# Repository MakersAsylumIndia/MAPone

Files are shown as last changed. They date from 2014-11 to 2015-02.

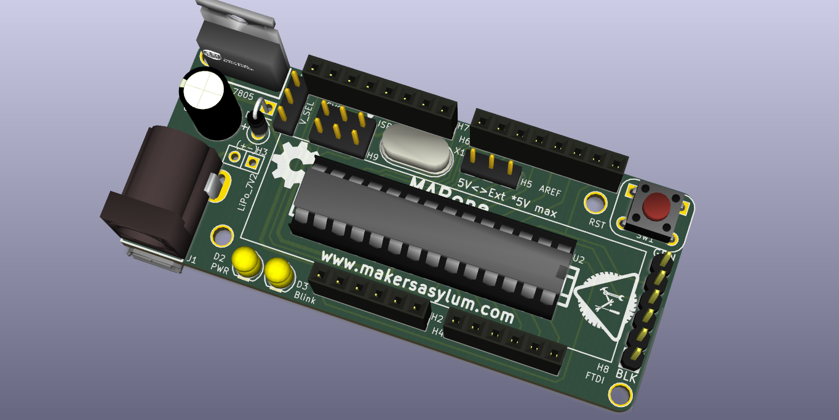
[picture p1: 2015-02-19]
images/MAPone_20.png

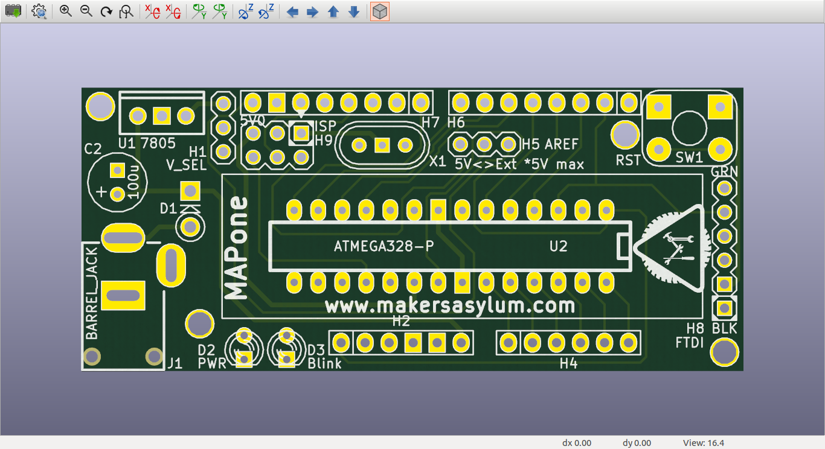
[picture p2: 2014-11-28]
images/MAPone_06.png

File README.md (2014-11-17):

MAPone
======

A really bare bones Arduino using ATMega 328P DIP, SPI and Serial Interfaces and a few LEDs. Arduino stripped down to bare basics so everyone can afford it.

License
-------
[CERN Open Hardware Licence v1.2 ]

[CERN Open Hardware Licence v1.2 ]:http://www.ohwr.org/attachments/2388/cern_ohl_v_1_2.txt

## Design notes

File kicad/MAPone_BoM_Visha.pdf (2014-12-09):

MAPone_BoM

Qty Catalog | Part Value | Part Package | Link
1 | 5 Capacitor | 100nF, 50V | CL21B104KBCNNNC
2 | 1 Capacitor | 100uF, 35V | Kemet | ESK107M035AE3AA
3 | 2 Capacitor | 22pF, 50V | CL21C220JBANFNC
4 | 1 Diode | 1N4007 | 1N4007-TP
5 | 1 Led | LED PWR | Kingbright | WP710A10ID
6 | 1 Led | LED_BLINK | Kingbright | WP710A10GD
7 | 1 Connector | BARREL_JACK | CUI Inc | PJ-002A

Item
No

Part
Description

Manufacturers
Name

Manufacturers
Part No.

CAP CER
0.1UF 50V
10% X7R 0805

0805
(2012 Metric)

Samsung
Electro-Mechanics
America, Inc

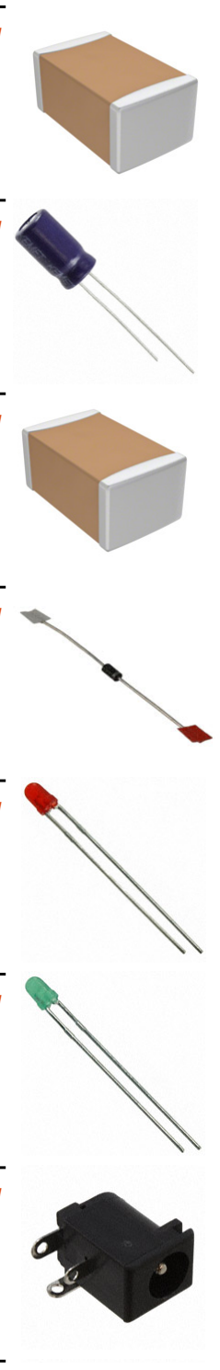
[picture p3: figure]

http://www.digikey.com/product-detail/en/CL21B104KBCNNNC/1276-1003-1-ND/3889089

CAP ALUM
100UF 35V
20% RADIAL

2.5mm pitch,
Radial

http://www.digikey.com/product-detail/en/ESK107M035AE3AA/399-6104-ND/2712510

CAP CER
22PF 50V
5% NP0 0805

0805
(2012 Metric)

Samsung
Electro-Mechanics
America, Inc

http://www.digikey.com/product-detail/en/CL21C220JBANFNC/1276-2606-1-ND/3890692

DIODE GEN
PURPOSE
1000V 1A DO41

DO-204AL,
DO-41,
Axial

Micro
Commercial Co

http://www.digikey.com/product-detail/en/1N4007-TP/1N4007-TPMSCT-ND/773694

LED RED DIFF
3MM 625NM

Round with
Domed Top,
3mm, T-1

http://www.digikey.com/product-detail/en/WP710A10ID/754-1606-ND/2769809

LED GREEN DIFF
3MM 568NM

Round with
Domed Top,
3mm, T-1

http://www.digikey.com/product-detail/en/WP710A10GD/754-1603-ND/2769808

CONN POWER JACK
2.1MM X 5.5MM

2.1mm ID,
5.5mm OD,
3 terminals

http://www.digikey.com/product-detail/en/PJ-002A/CP-002A-ND/96962

8 | 1 Connector | USB_Micro | FCI | 10118193-0001LF
9 | 1 Resistor | 10k | RMCF0805FT10K0
10 | 2 Resistor | 300E | ERJ-6GEYJ301V
11 | 1 Switch | SW_RST | 6.00mm x 6.00mm | 1825910-6
12 | 1 IC | 7805 | TO-220-3 | NCP7805TG
13 | 1 IC | Atmega328p | Atmel | ATMEGA328-PU
14 | 1 Crystal | Xtal_16MHz | 9B-16.000MBBK-B
15 | 1 Connector | PREC040SAAN-RC

CONN USB MICRO B
RECPT SMT R/A

Surface Mount,
Right Angle,
Horizontal
REFER DATA
SHEET

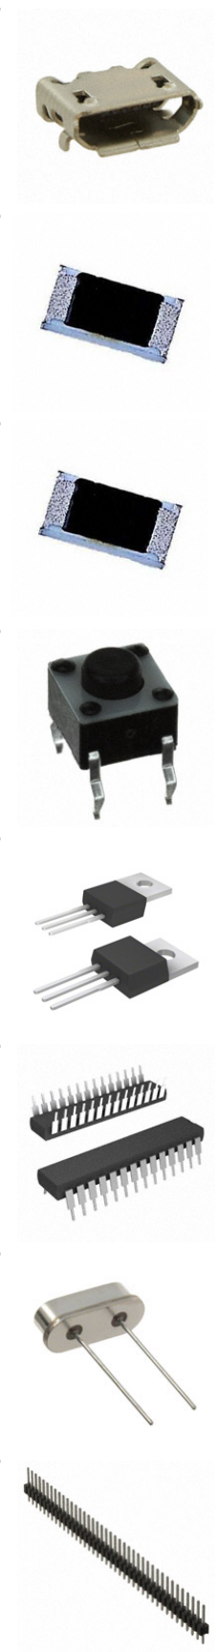
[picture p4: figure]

http://www.digikey.com/product-detail/en/10118193-0001LF/609-4616-1-ND/2785380

RES SMD 10K OHM
1% 1/8W 0805

0805
(2012 Metric)

Stackpole
Electronics
Inc

http://www.digikey.com/product-detail/en/RMCF0805FT10K0/RMCF0805FT10K0CT-ND/1942435

RES SMD 300 OHM
5% 1/8W 0805

0805
(2012 Metric)

Panasonic
Electronic
Components

http://www.digikey.com/product-detail/en/ERJ-6GEYJ301V/P300ACT-ND/90024

SWITCH TACTILE
SPST-NO
0.05A 12V

TE
Connectivity

http://www.digikey.com/product-detail/en/1825910-6/450-1650-ND/1632536

IC REG LDO
5V 1A TO220AB

ON
Semiconductor

http://www.digikey.com/product-detail/en/NCP7805TG/NCP7805TGOS-ND/2271529

IC MCU 8BIT 32KB
FLASH 28DIP

28-DIP
(0.300", 7.62mm)

http://www.digikey.com/product-detail/en/ATMEGA328-PU/ATMEGA328-PU-ND/2271026

CRYSTAL
16MHZ 20PF
THRU HOLE

Through Hole,
HC49/US, 0.2”
pitch

TXC
CORPORATION

http://www.digikey.com/product-detail/en/9B-16.000MBBK-B/887-2015-ND/3522089

Male Header,
0.1”

V_SEL, AREF,
FTDI

Header,
Unshrouded,
male,
0.100" (2.54mm)

Sullins
Connector
Solutions

http://www.digikey.com/product-detail/en/PREC040SAAN-RC/S1012EC-40-ND/2774814

16 | 2 Connector | PPTC061LFBN-RC
17 | 1 Connector | ISCP | PREC003DAAN-RC
18 | 2 Connector | IO_L, IO_H | PPTC081LFBN-RC
19 | 1 Socket | -- | ED281DT

CONN HEADER
FEMALE 6POS .1"
TIN

Power,
Analog

Through Hole,
Female Socket,
0.100" (2.54mm)

Sullins
Connector
Solutions

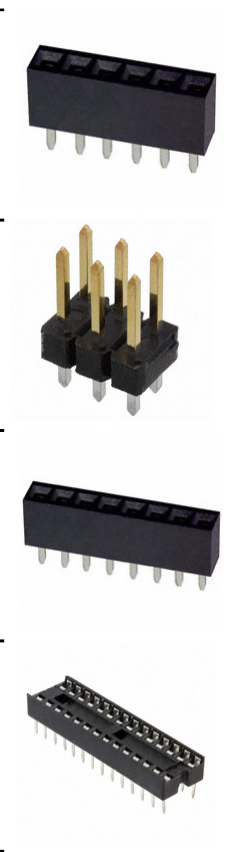
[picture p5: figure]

http://www.digikey.com/product-detail/en/PPTC061LFBN-RC/S7004-ND/810145

CONN HEADER
0.100"
DUAL STR 6POS

Header,
Unshrouded,
male,
0.100" (2.54mm),
3x2

Sullins
Connector
Solutions

http://www.digikey.com/product-detail/en/PREC003DAAN-RC/S2012EC-03-ND/2774891

CONN HEADER
FEMALE 8POS
0.1" TIN

Through Hole,
Female Socket,
0.100" (2.54mm)

Sullins
Connector
Solutions

http://www.digikey.com/product-detail/en/PPTC081LFBN-RC/S7006-ND/810147

CONN IC SOCKET
VERT 28POS TIN

IC socket,
28 pin,
0.3”

On Shore
Technology Inc

http://www.digikey.com/product-detail/en/ED281DT/ED3050-5-ND/4147600

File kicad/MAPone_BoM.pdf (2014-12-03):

MAPone_BoM

Qty Catalog | Link
| | | $1.00 | | $14.23 | | $8.65
| | | ₹60.00 | | ₹853.80 | | ₹519.17
1 | 5 Capacitor | CL21B104KBCNNNC Digikey | 1276-1003-1-ND | 0.10 | 0.50 | 0.0209 | 0.105 (http://www.digikey.com/product-detail/en/CL21B104KBCNNNC/1276-1003-1-ND/3889089)
2 | C2 | 1 Capacitor | 2.5mm pitch Kemet | ESK107M035AE3AA Digikey | 399-6104-ND | 0.21 | 0.21 | 0.0711 | 0.071 (http://www.digikey.com/product-detail/en/ESK107M035AE3AA/399-6104-ND/2712510)
3 | C7,C8 | 2 Capacitor | | CL21C220JBANFNC Digikey | 1276-2606-1-ND | 0.10 | 0.20 | 0.0220 | 0.044 (http://www.digikey.com/product-detail/en/CL21C220JBANFNC/1276-2606-1-ND/3890692)
4 | D1 | 1 Diode | 1N4007 | 1N4007-TP | Digikey | 1N4007-TPMSCT-ND 0.11 | 0.11 | 0.0649 | 0.065 (http://www.digikey.com/product-detail/en/1N4007-TP/1N4007-TPMSCT-ND/773694)
5 | D2 | 1 Led | LED PWR | Kingbright | WP710A10ID | Digikey | 754-1606-ND | 0.13 | 0.13 | 0.0715 | 0.072 (http://www.digikey.com/product-detail/en/WP710A10ID/754-1606-ND/2769809)
6 | D3 | 1 Led | | Kingbright | WP710A10GD | Digikey | 754-1603-ND | 0.13 | 0.13 | 0.0715 | 0.072 (http://www.digikey.com/product-detail/en/WP710A10GD/754-1603-ND/2769808)
7 | J1 | 1 Connector | | CUI Inc | PJ-047A | Digikey | CP-047A-ND | 0.97 | 0.97 | 0.5740 | 0.574 (http://www.digikey.com/product-detail/en/PJ-047A/CP-047A-ND/1644575)
8 | J2 | 1 Connector | FCI | 10118193-0001LF Digikey | 609-4616-1-ND | 0.46 | 0.46 | 0.3032 | 0.303 (http://www.digikey.com/product-detail/en/10118193-0001LF/609-4616-1-ND/2785380)
9 | R1 | 1 Resistor | 10k | CF18JT10K0 | Digikey | CF18JT10K0CT-ND | 0.10 | 0.10 | 0.0271 | 0.027 (http://www.digikey.com/product-detail/en/CF18JT10K0/CF18JT10K0CT-ND/2022766)
10 R2,R3 | 2 Resistor | 300E | CF18JT300R | Digikey | CF18JT300RCT-ND | 0.10 | 0.20 | 0.0271 | 0.054 (http://www.digikey.com/product-detail/en/CF18JT300R/CF18JT300RCT-ND/2022729)

Item
No

Refer
ence

Part
Descripti
on

Part
Value

Part
Package

Manufacture
rs Name

Manufacturers
Part No.

Distribu
tors
Name

Distributors
Part No.

Unit
Pric
e

Total
Price

Notes/
Remark

Extended
Price
(100
nos)

Total
Extended
Price
(100
nos)

C1,C3,
C4,C5,
C6

CAP CER
0.1UF 50V
10% X7R
0805

100nF,
50V

0805 (2012
Metric)

Samsung
Electro-Mechanics
America, Inc

http://www.digikey.com/product-detail/en/CL21B104KBCNNNC/1276-1003-1-ND/3889089

CAP ALUM
100UF 35V
20% RADIAL

100uF,
35V

http://www.digikey.com/product-detail/en/ESK107M035AE3AA/399-6104-ND/2712510

CAP CER
22PF 50V
5% NP0
0805

22pF,
50V

0805 (2012
Metric)

Samsung
Electro-Mechanics
America, Inc

http://www.digikey.com/product-detail/en/CL21C220JBANFNC/1276-2606-1-ND/3890692

DIODE GEN
PURPOSE
1000V 1A
DO41

DO-204AL,
DO-41,
Axial

Micro
Commercial
Co

http://www.digikey.com/product-detail/en/1N4007-TP/1N4007-TPMSCT-ND/773694

LED RED
DIFF 3MM
625NM

Round with
Domed Top,
3mm, T-1

http://www.digikey.com/product-detail/en/WP710A10ID/754-1606-ND/2769809

LED GREEN
DIFF 3MM
568NM

LED_BLIN
K

Round with
Domed Top,
3mm, T-1

http://www.digikey.com/product-detail/en/WP710A10GD/754-1603-ND/2769808

CON PWR
JCK 2.0 X
6.0MM
W/SHLD

BARREL_J
ACK

2.1mm ID,
5.5mm OD

http://www.digikey.com/product-detail/en/PJ-047A/CP-047A-ND/1644575

CONN USB
MICRO B
RECPT SMT
R/A

USB_Micr
o

Surface
Mount,
Right
Angle,
Horizontal

http://www.digikey.com/product-detail/en/10118193-0001LF/609-4616-1-ND/2785380

RES 10K
OHM 1/8W
5% CF
AXIAL

Axial,
0.125W,
1/8W

Stackpole
Electronics
Inc

http://www.digikey.com/product-detail/en/CF18JT10K0/CF18JT10K0CT-ND/2022766

RES 300
OHM 1/8W
5% CF
AXIAL

Axial,
0.125W,
1/8W

Stackpole
Electronics
Inc

http://www.digikey.com/product-detail/en/CF18JT300R/CF18JT300RCT-ND/2022729

MAPone_BoM

11 SW1 | 1 Switch | SW_RST | 1825910-6 | Digikey | 450-1650-ND | 0.10 | 0.10 | 0.8190 | 0.819 (http://www.digikey.com/product-detail/en/1825910-6/450-1650-ND/1632536)
12 U1 | 1 IC | 7805 TO-220-3 | NCP7805TG | Digikey | NCP7805TGOS-ND | 0.46 | 0.46 | 0.2934 | 0.293 (http://www.digikey.com/product-detail/en/NCP7805TG/NCP7805TGOS-ND/2271529)
13 U2 | 1 IC | Atmel | ATMEGA328-PU | Digikey | ATMEGA328-PU-ND | 3.41 | 3.41 | 2.4970 | 2.497 (http://www.digikey.com/product-detail/en/ATMEGA328-PU/ATMEGA328-PU-ND/2271026)
14 X1 | 1 Crystal Xtal_16MHz | 9B-16.000MBBK-B Digikey | 887-2015-ND | 0.33 | 0.33 | 0.2200 | 0.220 (http://www.digikey.com/product-detail/en/9B-16.000MBBK-B/887-2015-ND/3522089)
15 | 1 Connector | PREC040SAAN-RC | Digikey | S1012EC-40-ND | 0.56 | 0.56 | 0.4160 | 0.416 (http://www.digikey.com/product-detail/en/PREC040SAAN-RC/S1012EC-40-ND/2774814)
16 H2, H4 2 Connector | PPTC061LFBN-RC | Digikey | S7004-ND | 0.68 | 1.36 | 0.4028 | 0.806 (http://www.digikey.com/product-detail/en/PPTC061LFBN-RC/S7004-ND/810145)
17 H9 | 1 Connector | ISCP | PREC003DAAN-RC | Digikey | S2012EC-03-ND | 0.28 | 0.28 | 0.2033 | 0.203 (http://www.digikey.com/product-detail/en/PREC003DAAN-RC/S2012EC-03-ND/2774891)
18 H6, H7 2 Connector | PPTC081LFBN-RC | Digikey | S7006-ND | 0.86 | 1.72 | 0.5063 | 1.013 (http://www.digikey.com/product-detail/en/PPTC081LFBN-RC/S7006-ND/810147)
19 PCB | 1 -- | MAPone | -- | seeed studio Fusion Service | seeed stud-- | 3.00 | 3.00 | 1.0000 | 1.000 (http://www.seeedstudio.com/service/index.php?r=pcb)

SWITCH
TACTILE
SPST-NO
0.05A 12V

6.00mm x
6.00mm

TE
Connectivity

http://www.digikey.com/product-detail/en/1825910-6/450-1650-ND/1632536

IC REG LDO
5V 1A
TO220AB

ON
Semiconducto
r

http://www.digikey.com/product-detail/en/NCP7805TG/NCP7805TGOS-ND/2271529

IC MCU
8BIT 32KB
FLASH
28DIP

28-DIP
(0.300",
7.62mm)

http://www.digikey.com/product-detail/en/ATMEGA328-PU/ATMEGA328-PU-ND/2271026

CRYSTAL
16MHZ
20PF
THRU

Through
Hole,
HC49/US

TXC
CORPORATION

http://www.digikey.com/product-detail/en/9B-16.000MBBK-B/887-2015-ND/3522089

H1,
H3,
H5,
H8,

Male
Header,
0.1”

V_SEL,
AREF,
FTDI

Header,
unshrouded,
male,
0.100"
(2.54mm)

Sullins
Connector
Solutions

http://www.digikey.com/product-detail/en/PREC040SAAN-RC/S1012EC-40-ND/2774814

CONN
HEADER
FEMALE
6POS .1"
TIN

Power,
Analog

Through
Hole,
Female
Socket,
0.100"
(2.54mm)

Sullins
Connector
Solutions

http://www.digikey.com/product-detail/en/PPTC061LFBN-RC/S7004-ND/810145

CONN
HEADER .
100" DUAL
STR 6POS

Header,
unshrouded,
male,
0.100"
(2.54mm),
3x2

Sullins
Connector
Solutions

http://www.digikey.com/product-detail/en/PREC003DAAN-RC/S2012EC-03-ND/2774891

CONN
HEADER
FEMALE
8POS .1"
TIN

IO_L,
IO_H

Through
Hole,
Female
Socket,
0.100"
(2.54mm)

Sullins
Connector
Solutions

http://www.digikey.com/product-detail/en/PPTC081LFBN-RC/S7006-ND/810147

Yellow
Mask,
Black
Legend

http://www.seeedstudio.com/service/index.php?r=pcb

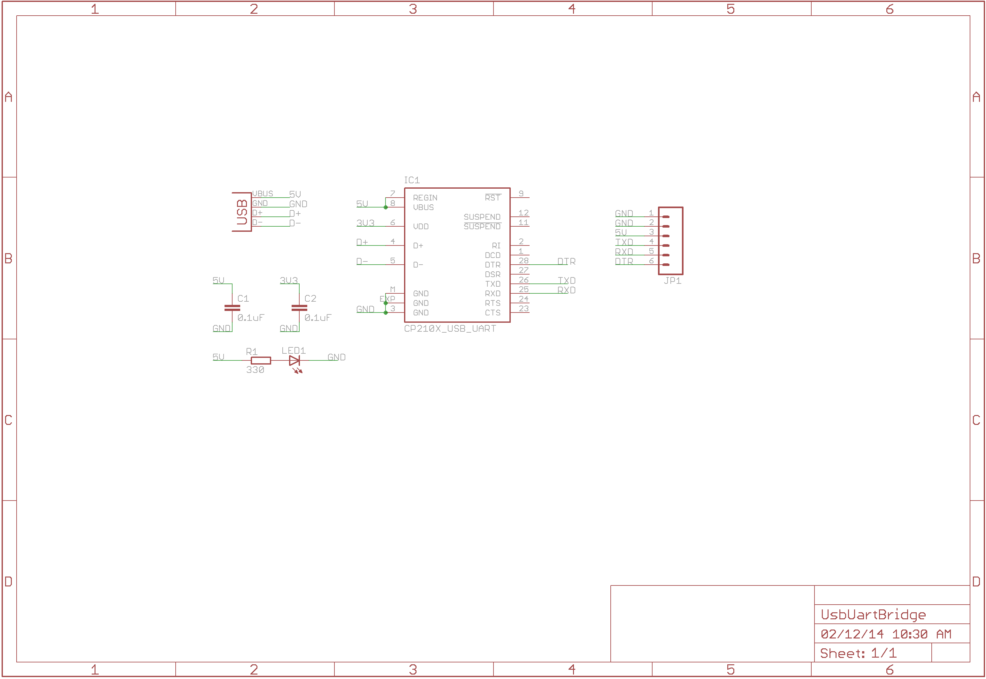
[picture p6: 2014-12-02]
Eagle/USB-UART Bridge/schematic.png

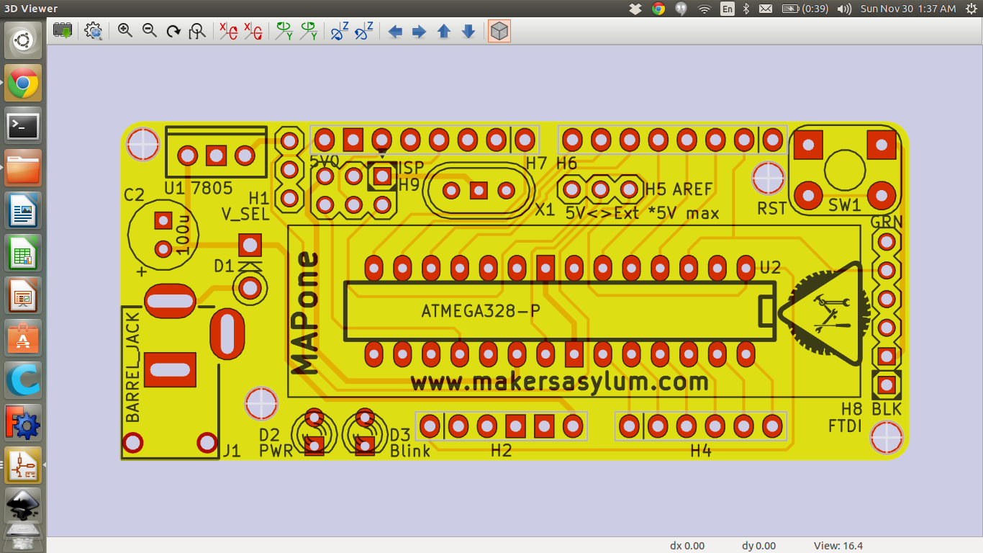
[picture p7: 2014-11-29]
images/MAPone_11.png

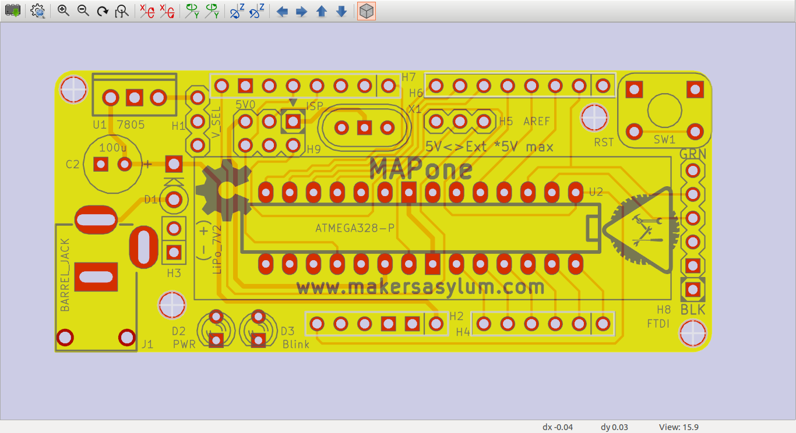
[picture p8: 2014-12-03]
images/MAPone_17.png

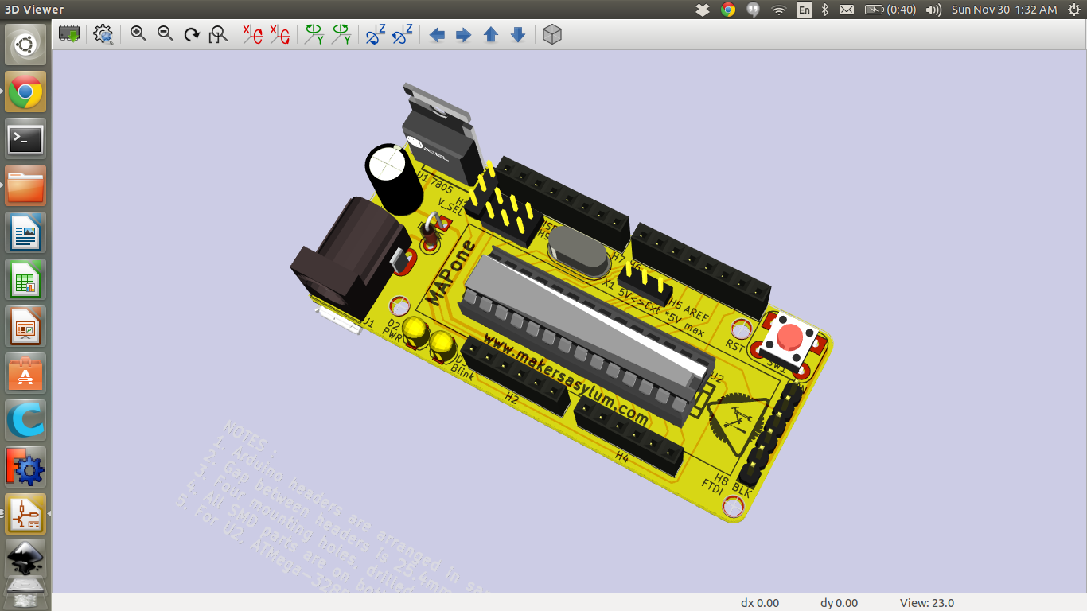
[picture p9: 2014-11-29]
images/MAPone_07.png

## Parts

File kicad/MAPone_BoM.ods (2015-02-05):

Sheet: MAPone_BoM
Item No | Reference | Qty | Catalog | Part Description | Part Value | Part Package | Manufacturers Name | Manufacturers Part No. | Distributors Name | Distributors Part No. | Unit Price | Total Price | Notes/Remark | Link | Extended Price (100 nos) | Total Extended Price (100 nos)
 |  |  |  |  |  |  |  |  |  | $1.00 |  | $14.19 |  |  |  | $8.48
 |  |  |  |  |  |  |  |  |  | ₹60.00 |  | ₹851.40 |  |  |  | ₹508.61
1 | C1,C3,C4,C5,C6 | 5 | Capacitor | CAP CER 0.1UF 50V 10% X7R 0805 | 100nF, 50V | 0805 (2012 Metric) | Samsung Electro-Mechanics America, Inc | CL21B104KBCNNNC | Digikey | 1276-1003-1-ND | 0.10 | 0.50 |  | http://www.digikey.com/product-detail/en/CL21B104KBCNNNC/1276-1003-1-ND/3889089 | 0.0209 | 0.105
2 | C2 | 1 | Capacitor | CAP ALUM 100UF 35V 20% RADIAL | 100uF, 35V | 2.5mm pitch | Kemet | ESK107M035AE3AA | Digikey | 399-6104-ND | 0.21 | 0.21 |  | http://www.digikey.com/product-detail/en/ESK107M035AE3AA/399-6104-ND/2712510 | 0.0711 | 0.071
3 | C7,C8 | 2 | Capacitor | CAP CER 22PF 50V 5% NP0 0805 | 22pF, 50V | 0805 (2012 Metric) | Samsung Electro-Mechanics America, Inc | CL21C220JBANFNC | Digikey | 1276-2606-1-ND | 0.10 | 0.20 |  | http://www.digikey.com/product-detail/en/CL21C220JBANFNC/1276-2606-1-ND/3890692 | 0.0220 | 0.044
4 | D1 | 1 | Diode | DIODE GEN PURPOSE 1000V 1A DO41 | 1N4007 | DO-204AL, DO-41, Axial | Micro Commercial Co | 1N4007-TP | Digikey | 1N4007-TPMSCT-ND | 0.11 | 0.11 |  | http://www.digikey.com/product-detail/en/1N4007-TP/1N4007-TPMSCT-ND/773694 | 0.0649 | 0.065
5 | D2 | 1 | Led | LED RED DIFF 3MM 625NM | LED PWR | Round with Domed Top, 3mm, T-1 | Kingbright | WP710A10ID | Digikey | 754-1606-ND | 0.13 | 0.13 |  | http://www.digikey.com/product-detail/en/WP710A10ID/754-1606-ND/2769809 | 0.0715 | 0.072
6 | D3 | 1 | Led | LED GREEN DIFF 3MM 568NM | LED_BLINK | Round with Domed Top, 3mm, T-1 | Kingbright | WP710A10GD | Digikey | 754-1603-ND | 0.13 | 0.13 |  | http://www.digikey.com/product-detail/en/WP710A10GD/754-1603-ND/2769808 | 0.0715 | 0.072
7 | J1 | 1 | Connector | CONN POWER JACK 2.1MM | BARREL_JACK | 2.1mm ID, 5.5mm OD | CUI Inc | PJ-002A | Digikey | CP-002A-ND | 0.93 | 0.93 |  | http://www.digikey.com/product-detail/en/PJ-002A/CP-002A-ND/96962 | 0.4371 | 0.437
8 | J2 | 1 | Connector | CONN USB MICRO B RECPT SMT R/A | USB_Micro | Surface Mount, Right Angle, Horizontal | FCI | 10118193-0001LF | Digikey | 609-4616-1-ND | 0.46 | 0.46 |  | http://www.digikey.com/product-detail/en/10118193-0001LF/609-4616-1-ND/2785380 | 0.3032 | 0.303
9 | R1 | 1 | Resistor | RES SMD 10K OHM 1% 1/8W 0805 | 10k | 0805 (2012 Metric) | Stackpole Electronics Inc | RMCF0805FT10K0 | Digikey | RMCF0805FT10K0CT-ND | 0.10 | 0.10 |  | http://www.digikey.com/product-detail/en/RMCF0805FT10K0/RMCF0805FT10K0CT-ND/1942435 | 0.0123 | 0.012
10 | R2,R3 | 2 | Resistor | RES SMD 300 OHM 5% 1/8W 0805 | 300E | 0805 (2012 Metric) | Panasonic Electronic Components | ERJ-6GEYJ301V | Digikey | P300ACT-ND | 0.10 | 0.20 |  | http://www.digikey.com/product-detail/en/ERJ-6GEYJ301V/P300ACT-ND/90024 | 0.0149 | 0.030
11 | SW1 | 1 | Switch | SWITCH TACTILE SPST-NO 0.05A 12V | SW_RST | 6.00mm x 6.00mm | TE Connectivity | 1825910-6 | Digikey | 450-1650-ND | 0.10 | 0.10 |  | http://www.digikey.com/product-detail/en/1825910-6/450-1650-ND/1632536 | 0.8190 | 0.819
12 | U1 | 1 | IC | IC REG LDO 5V 1A TO220AB | 7805 | TO-220-3 | ON Semiconductor | NCP7805TG | Digikey | NCP7805TGOS-ND | 0.46 | 0.46 |  | http://www.digikey.com/product-detail/en/NCP7805TG/NCP7805TGOS-ND/2271529 | 0.2934 | 0.293
13 | U2 | 1 | IC | IC MCU 8BIT 32KB FLASH 28DIP |  | 28-DIP (0.300", 7.62mm) | Atmel | ATMEGA328-PU | Digikey | ATMEGA328-PU-ND | 3.41 | 3.41 |  | http://www.digikey.com/product-detail/en/ATMEGA328-PU/ATMEGA328-PU-ND/2271026 | 2.4970 | 2.497
14 | X1 | 1 | Crystal | Xtal_16MHz | CRYSTAL 16MHZ 20PF THRU | Through Hole, HC49/US | TXC CORPORATION | 9B-16.000MBBK-B | Digikey | 887-2015-ND | 0.33 | 0.33 |  | http://www.digikey.com/product-detail/en/9B-16.000MBBK-B/887-2015-ND/3522089 | 0.2200 | 0.220
15 | H1, H3, H5, H8, | 1 | Connector | Male Header, 0.1” | V_SEL, AREF, FTDI | Header, unshrouded, male, 0.100" (2.54mm) | Sullins Connector Solutions | PREC040SAAN-RC | Digikey | S1012EC-40-ND | 0.56 | 0.56 |  | http://www.digikey.com/product-detail/en/PREC040SAAN-RC/S1012EC-40-ND/2774814 | 0.4160 | 0.416
16 | H2, H4 | 2 | Connector | CONN HEADER FEMALE 6POS .1" TIN | Power, Analog | Through Hole, Female Socket, 0.100" (2.54mm) | Sullins Connector Solutions | PPTC061LFBN-RC | Digikey | S7004-ND | 0.68 | 1.36 |  | http://www.digikey.com/product-detail/en/PPTC061LFBN-RC/S7004-ND/810145 | 0.4028 | 0.806
17 | H9 | 1 | Connector | CONN HEADER .100" DUAL STR 6POS | ISCP | Header, unshrouded, male, 0.100" (2.54mm), 3x2 | Sullins Connector Solutions | PREC003DAAN-RC | Digikey | S2012EC-03-ND | 0.28 | 0.28 |  | http://www.digikey.com/product-detail/en/PREC003DAAN-RC/S2012EC-03-ND/2774891 | 0.2033 | 0.203
18 | H6, H7 | 2 | Connector | CONN HEADER FEMALE 8POS .1" TIN | IO_L, IO_H | Through Hole, Female Socket, 0.100" (2.54mm) | Sullins Connector Solutions | PPTC081LFBN-RC | Digikey | S7006-ND | 0.86 | 1.72 |  | http://www.digikey.com/product-detail/en/PPTC081LFBN-RC/S7006-ND/810147 | 0.5063 | 1.013
19 | PCB | 1 | -- | Yellow Mask, Black Legend | MAPone | -- | seeed studio | Fusion Service | seeed studio | -- | 3.00 | 3.00 |  | http://www.seeedstudio.com/service/index.php?r=pcb | 1.0000 | 1.000

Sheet: MAPone_BoM_pcb
Id | Designator | Package | Quantity | Designation
1 | C1,C3,C4,C5,C6 | C_0805_HandSoldering | 5 | 100n
2 | C2 | Elko_vert_11.2x6.3mm_RM2.5 | 1 | 100u
3 | C7,C8 | C_0805_HandSoldering | 2 | 22pF
4 | D1 | Diode_DO-41_SOD81_Vertical_KathodeUp | 1 | 1N4007
5 | D2 | LED-3MM | 1 | PWR
6 | D3 | LED-3MM | 1 | Blink
7 | H1 | Header_3 | 1 | V_SEL
8 | H2 | Socket_Strip_Straight_1x06 | 1 | Power
 | H3 | Pin_Header_Straight_1x02 | 1 | LiPo_7V2
 | H4 | Socket_Strip_Straight_1x06 | 1 | ANALOG
 | H5 | Header_A_REF | 1 | AREF
9 | H6 | Socket_Strip_Straight_1x08 | 1 | IO_L
 | H7 | Socket_Strip_Straight_1x08 | 1 | IO_H
 | H8 | Header_FTDI | 1 | FTDI
10 | H9 | Header_ICSP | 1 | ISP
11 | J1 | JACK_ALIM | 1 | BARREL_JACK
12 | R1 | R_0805_HandSoldering | 1 | 10k
13 | R2,R3 | R_0805_HandSoldering | 2 | 300E
14 | SW1 | SW-PB | 1 | RST
15 | U1 | LM78XXV | 1 | 7805
16 | U2 | DIP-28__300_ELL_ZIF | 1 | ATMEGA328-P
17 | X1 | Crystal_HC49-U_Vertical_3Pin | 1 | 16MHz
18 | J2 | USB_B_Micro | 1 | USB-Micro
24 | P1,P2,P3,P4 | vite_3mm | 4 | CONN_1
25 | Z1,Z2 | MA_Logo2 | 2 | CONN_1
26 | Z6,Z7 | OSHW_6mm | 2 | CONN_1

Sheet: MAPone_BoM_sch
Reference | Value | Footprint | Datasheet | DigiKey
C1 | 100n | MAPone.pretty:C_0805_HandSoldering
C2 | 100u | MAPone.pretty:Elko_vert_11.2x6.3mm_RM2.5
C3 | 100n | MAPone.pretty:C_0805_HandSoldering
C4 | 100n | MAPone.pretty:C_0805_HandSoldering
C5 | 100n | MAPone.pretty:C_0805_HandSoldering
C6 | 100n | MAPone.pretty:C_0805_HandSoldering
C7 | 22pF | MAPone.pretty:C_0805_HandSoldering
C8 | 22pF | MAPone.pretty:C_0805_HandSoldering
D1 | 1N4007 | MAPone.pretty:Diode_DO-41_SOD81_Vertical_KathodeUp
D2 | PWR | MAPone.pretty:LED-3MM
D3 | Blink | MAPone.pretty:LED-3MM
H1 | V_SEL | MAPone.pretty:Header_3
H2 | Power | MAPone.pretty:Socket_Strip_Straight_1x06
H3 | LiPo_7V2 | MAPone.pretty:Pin_Header_Straight_1x02
H4 | ANALOG | MAPone.pretty:Socket_Strip_Straight_1x06
H5 | AREF | MAPone.pretty:Header_A_REF
H6 | IO_L | MAPone.pretty:Socket_Strip_Straight_1x08
H7 | IO_H | MAPone.pretty:Socket_Strip_Straight_1x08
H8 | FTDI | MAPone.pretty:Header_FTDI
H9 | ISP | MAPone.pretty:Header_ICSP
J1 | BARREL_JACK | MAPone.pretty:JACK_ALIM
J2 | USB-Micro | MAPone.pretty:USB_B_Micro
P1 | CONN_1 | MAPone.pretty:vite_3mm
P2 | CONN_1 | MAPone.pretty:vite_3mm
P3 | CONN_1 | MAPone.pretty:vite_3mm
P4 | CONN_1 | MAPone.pretty:vite_3mm
R1 | 10k | MAPone.pretty:R_0805_HandSoldering
R2 | 300E | MAPone.pretty:R_0805_HandSoldering
R3 | 300E | MAPone.pretty:R_0805_HandSoldering
SW1 | RST | MAPone.pretty:SW-PB | http://industrial.panasonic.com/www-data/pdf/ATK0000/ATK0000CE32.pdf | P10884S-ND
U1 | 7805 | MAPone.pretty:LM78XXV
U2 | ATMEGA328-P | MAPone.pretty:DIP-28__300_ELL_ZIF
X1 | 16MHz | MAPone.pretty:Crystal_HC49-U_Vertical_3Pin | http://search.murata.co.jp/Ceramy/image/img/w_hinm/L0430E.pdf | 490-1214-ND
Z1 | CONN_1 | MAPone.pretty:MA_Logo2
Z2 | CONN_1 | MAPone.pretty:MA_Logo2
Z6 | CONN_1 | MAPone:OSHW_6mm
Z7 | CONN_1 | MAPone:OSHW_6mm

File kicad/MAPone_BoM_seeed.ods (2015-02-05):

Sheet: Seeed BOM Format
Electronic Engineering BOM List
Product Name： MAPone : Maker's Asylum, Mumbai, India
Version：V1.0
Issue Date：17/12/2014
Item No. (序号) | Reference Des (上件位置) | Qty (用量) | Catalog (分类） | Part_Description (规格描述) | Part_Value （元件值） | Part_Package （元件封装） | Manufacturers Name (使用厂牌名称) | Manufacturers Part No. (使用厂牌型号) | Distributors Name （供应商名称） | Distributors Part No. (供貨商型号) | Unit Price （单价） | Price Break To Use （价格分段的购买量） | Notes/Remark （备注）
Example（填写范例）
1 | C1,C3,C4,C5,C6 | 5 | Capacitor | CAP CER 0.1UF 50V 10% X7R 0805 | 100nF, 50V | 0805 (2012 Metric) | Samsung Electro-Mechanics America, Inc | CL21B104KBCNNNC | Digikey | 1276-1003-1-ND |  |  | http://www.digikey.com/product-detail/en/CL21B104KBCNNNC/1276-1003-1-ND/3889089
2 | C2 | 1 | Capacitor | CAP ALUM 100UF 35V 20% RADIAL | 100uF, 35V | 2.5mm pitch | Kemet | ESK107M035AE3AA | Digikey | 399-6104-ND |  |  | http://www.digikey.com/product-detail/en/ESK107M035AE3AA/399-6104-ND/2712510
3 | C7,C8 | 2 | Capacitor | CAP CER 22PF 50V 5% NP0 0805 | 22pF, 50V | 0805 (2012 Metric) | Samsung Electro-Mechanics America, Inc | CL21C220JBANFNC | Digikey | 1276-2606-1-ND |  |  | http://www.digikey.com/product-detail/en/CL21C220JBANFNC/1276-2606-1-ND/3890692
4 | D1 | 1 | Diode | DIODE GEN PURPOSE 1000V 1A DO41 | 1N4007 | DO-204AL, DO-41, Axial | Micro Commercial Co | 1N4007-TP | Digikey | 1N4007-TPMSCT-ND |  |  | http://www.digikey.com/product-detail/en/1N4007-TP/1N4007-TPMSCT-ND/773694
5 | D2 | 1 | Diode | LED RED DIFF 3MM 625NM | LED PWR | Round with Domed Top, 3mm, T-1 | Kingbright | WP710A10ID | Digikey | 754-1606-ND |  |  | http://www.digikey.com/product-detail/en/WP710A10ID/754-1606-ND/2769809
6 | D3 | 1 | Diode | LED GREEN DIFF 3MM 568NM | LED_BLINK | Round with Domed Top, 3mm, T-1 | Kingbright | WP710A10GD | Digikey | 754-1603-ND |  |  | http://www.digikey.com/product-detail/en/WP710A10GD/754-1603-ND/2769808
7 | J1 | 1 | Connector | CONN POWER JACK 2.1MM | BARREL_JACK | 2.1mm ID, 5.5mm OD | CUI Inc | PJ-002A | Digikey | CP-002A-ND |  |  | http://www.digikey.com/product-detail/en/PJ-002A/CP-002A-ND/96962
8 | J2 | 1 | Connector | CONN USB MICRO B RECPT SMT R/A | USB_Micro | Surface Mount, Right Angle, Horizontal | FCI | 10118193-0001LF | Digikey | 609-4616-1-ND |  |  | http://www.digikey.com/product-detail/en/10118193-0001LF/609-4616-1-ND/2785380
9 | R1 | 1 | Resister | RES SMD 10K OHM 1% 1/8W 0805 | 10k | 0805 (2012 Metric) | Stackpole Electronics Inc | RMCF0805FT10K0 | Digikey | RMCF0805FT10K0CT-ND |  |  | http://www.digikey.com/product-detail/en/RMCF0805FT10K0/RMCF0805FT10K0CT-ND/1942435
10 | R2,R3 | 2 | Resister | RES SMD 300 OHM 5% 1/8W 0805 | 300E | 0805 (2012 Metric) | Panasonic Electronic Components | ERJ-6GEYJ301V | Digikey | P300ACT-ND |  |  | http://www.digikey.com/product-detail/en/ERJ-6GEYJ301V/P300ACT-ND/90024
11 | SW1 | 1 | OTHER | SWITCH TACTILE SPST-NO 0.05A 12V | SW_RST | 6.00mm x 6.00mm | TE Connectivity | 1825910-6 | Digikey | 450-1650-ND |  |  | http://www.digikey.com/product-detail/en/1825910-6/450-1650-ND/1632536
12 | U1 | 1 | IC | IC REG LDO 5V 1A TO220AB | 7805 | TO-220-3 | ON Semiconductor | NCP7805TG | Digikey | NCP7805TGOS-ND |  |  | http://www.digikey.com/product-detail/en/NCP7805TG/NCP7805TGOS-ND/2271529
13 | U2 | 1 | IC | IC MCU 8BIT 32KB FLASH 28DIP | SW_RST | 28-DIP (0.300", 7.62mm) | Atmel | ATMEGA328-PU | Digikey | ATMEGA328-PU-ND |  |  | http://www.digikey.com/product-detail/en/ATMEGA328-PU/ATMEGA328-PU-ND/2271026
14 | X1 | 1 | OTHER | Xtal_16MHz | CRYSTAL 16MHZ 20PF THRU | Through Hole, HC49/US | TXC CORPORATION | 9B-16.000MBBK-B | Digikey | 887-2015-ND |  |  | http://www.digikey.com/product-detail/en/9B-16.000MBBK-B/887-2015-ND/3522089
15 | H1, H3, H5, H8, | 1 | Connector | Male Header, 0.1” | V_SEL, AREF, FTDI | Header, unshrouded, male, 0.100" (2.54mm) | Sullins Connector Solutions | PREC040SAAN-RC | Digikey | S1012EC-40-ND |  |  | http://www.digikey.com/product-detail/en/PREC040SAAN-RC/S1012EC-40-ND/2774814
16 | H2, H4 | 2 | Connector | CONN HEADER FEMALE 6POS .1" TIN | Power, Analog | Through Hole, Female Socket, 0.100" (2.54mm) | Sullins Connector Solutions | PPTC061LFBN-RC | Digikey | S7004-ND |  |  | http://www.digikey.com/product-detail/en/PPTC061LFBN-RC/S7004-ND/810145
17 | H9 | 1 | Connector | CONN HEADER .100" DUAL STR 6POS | ISCP | Header, unshrouded, male, 0.100" (2.54mm), 3x2 | Sullins Connector Solutions | PREC003DAAN-RC | Digikey | S2012EC-03-ND |  |  | http://www.digikey.com/product-detail/en/PREC003DAAN-RC/S2012EC-03-ND/2774891
18 | H6, H7 | 2 | Connector | CONN HEADER FEMALE 8POS .1" TIN | IO_L, IO_H | Through Hole, Female Socket, 0.100" (2.54mm) | Sullins Connector Solutions | PPTC081LFBN-RC | Digikey | S7006-ND |  |  | http://www.digikey.com/product-detail/en/PPTC081LFBN-RC/S7006-ND/810147
19 | -- | 1 | OTHER | CONN IC SOCKET VERT 28POS TIN | -- | DIP, 0.3" (7.62mm) Row Spacing | On Shore Technology Inc | ED281DT | Digikey | ED3050-5-ND |  |  | http://www.digikey.com/product-detail/en/ED281DT/ED3050-5-ND/4147600
1. Recommended Distributor: Digi-Key, Mouser, Avnet Express, Farnell.
2. Catalog: Capacitor,Resister,Diode,Connector,Transistor,IC,PROTECTOR CATEGORY,OTHER
3. Required Fields: Item No, Reference Des, Qty, Catalog, Part_Value, Part Package
Optional Fields: Part_Description, Manufacturers Name, Manufacturers Part No, Distributors Name, Distributors Part No, Unit Cost, Price break to use, Notes/Remark

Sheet: Sheet4
Id | Designator | Package | Quantity | Designation
1 | BT1 | C4_Pretty:CR2032_SMD | 1 | Batt_RTC
2 | C2,C4 | C4_Pretty:c_0805 | 2 | 100p
3 | C1,C3,C6,C8,C9,C11,C197,C198 | C4_Pretty:c_0805 | 8 | 100n
4 | C5,C7 | C4_Pretty:c_0805 | 2 | 22p
5 | C10,C194,C195,C196 | C4_Pretty:c_2917 | 4 | 47u
6 | C193 ~ C12 | C4_Pretty:c_0805_led | 182 | 100n
10 | LDR1 | C4_Pretty:r_0805 | 1 | LDR
11 | LED182 ~ LED1 | C4_Pretty:RGB_WS2811B | 182 | WS2812B
12 | P1 | C4_Pretty:ISP | 1 | ICSP
13 | P2 | C4_Pretty:Header_FTDI | 1 | FTDI
14 | P3 | C4_Pretty:SIL-2 | 1 | LDR_header
15 | P4 | C4_Pretty:SIL-2 | 1 | Button_Header
16 | P5 | C4_Pretty:JACK_PJ-047a | 1 | BARREL_JACK
17 | P6 | C4_Pretty:r_0805 | 1 | 5VEN_L
18 | P7 | C4_Pretty:STACK-L | 1 | I2C_L
19 | P8 | C4_Pretty:r_0805 | 1 | 5VEN_R
20 | P9 | C4_Pretty:STACK-R | 1 | I2C_R
21 | R1 | C4_Pretty:r_0805 | 1 | 500R
22 | R3,R4 | C4_Pretty:r_0805 | 2 | 1M
23 | R2,R5,R6,R7 | C4_Pretty:r_0805 | 4 | 10K
24 | R8,R9 | C4_Pretty:r_0805 | 2 | 4K7
25 | R12,R13 | C4_Pretty:r_0805 | 2 | 0R
26 | SW1 | C4_Pretty:SW_PB_V_H | 1 | SW_RST
27 | SW2 | C4_Pretty:SW_SMD | 1 | SW_L
28 | SW3 | C4_Pretty:SW_SMD | 1 | SW_R
29 | U1 | C4_Pretty:TQFP32 | 1 | ATMEGA328P
30 | U2 | C4_Pretty:DS3231 | 1 | DS3231N
31 | X1 | C4_Pretty:Xtal_SMD3 | 1 | 16MHz

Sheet: BoM_PCB
Id | Designator | Package | Quantity | Designation | Supplier and ref
1 | BT1 | C4_Pretty:CR2032_SMD | 1 | Batt_RTC
2 | C4,C2 | C4_Pretty:c_0805 | 2 | 100p
3 | C6,C8,C9,C3,C1,C11,C197,C198 | C4_Pretty:c_0805 | 8 | 100n
4 | C7,C5 | C4_Pretty:c_0805 | 2 | 22p
5 | C10,C196,C195,C194 | C4_Pretty:c_2917 | 4 | 47u
6 | C193,C192,C191,C190,C189,C188,C187,C186,C185,C184,C183,C182,C181,C180,C179,C178,C177,C176,C175,C174,C173,C172,C171,C170,C169,C168,C167,C166,C165,C164,C163,C162,C161,C160,C159,C158,C157,C156,C155,C154,C153,C152,C151,C150,C149,C148,C147,C146,C145,C144,C143,C142,C141,C140,C139,C138,C137,C136,C135,C134,C133,C132,C131,C130,C129,C128,C127,C126,C125,C124,C123,C122,C121,C120,C119,C118,C117,C116,C115,C114,C113,C112,C111,C110,C109,C108,C107,C106,C105,C104,C103,C102,C101,C100,C99,C98,C97,C96,C95,C94,C93,C92,C91,C90,C89,C88,C87,C86,C85,C84,C83,C82,C81,C80,C79,C78,C77,C76,C75,C74,C73,C72,C71,C70,C69,C68,C67,C66,C65,C64,C63,C62,C61,C60,C59,C58,C57,C56,C55,C54,C53,C52,C51,C50,C49,C48,C47,C46,C45,C44,C43,C42,C41,C40,C39,C38,C37,C36,C35,C34,C33,C32,C31,C30,C29,C28,C27,C26,C25,C24,C23,C22,C21,C20,C19,C18,C17,C16,C15,C14,C13,C12 | C4_Pretty:c_0805_led | 182 | 100n
7 | G1 | C4_Pretty:Logo-WL3 | 1 | Logo-WL3
8 | L1 | C4_Pretty:Logo_silk_OSHW_6x6mm | 1 | OSHW
9 | L2,L3 | C4_Pretty:Logo-WL3 | 1 | Wyolum
10 | LDR1 | C4_Pretty:r_0805 | 1 | LDR
11 | LED182,LED181,LED180,LED179,LED178,LED177,LED176,LED175,LED174,LED173,LED172,LED171,LED170,LED169,LED168,LED167,LED166,LED165,LED164,LED163,LED162,LED161,LED160,LED159,LED158,LED157,LED156,LED155,LED154,LED153,LED152,LED151,LED150,LED149,LED148,LED147,LED146,LED145,LED144,LED143,LED142,LED141,LED140,LED139,LED138,LED137,LED136,LED135,LED134,LED133,LED132,LED131,LED130,LED129,LED128,LED127,LED126,LED125,LED124,LED123,LED122,LED121,LED120,LED119,LED118,LED117,LED116,LED115,LED114,LED113,LED112,LED111,LED110,LED109,LED108,LED107,LED106,LED105,LED104,LED103,LED102,LED101,LED100,LED99,LED98,LED97,LED96,LED95,LED94,LED93,LED92,LED91,LED90,LED89,LED88,LED87,LED86,LED85,LED84,LED83,LED82,LED81,LED80,LED79,LED78,LED77,LED76,LED75,LED74,LED73,LED72,LED71,LED70,LED69,LED68,LED67,LED66,LED65,LED64,LED63,LED62,LED61,LED60,LED59,LED58,LED57,LED56,LED55,LED54,LED53,LED52,LED51,LED50,LED49,LED48,LED47,LED46,LED45,LED44,LED43,LED42,LED41,LED40,LED39,LED38,LED37,LED36,LED35,LED34,LED33,LED32,LED31,LED30,LED29,LED28,LED27,LED26,LED25,LED24,LED23,LED22,LED21,LED20,LED19,LED18,LED17,LED16,LED15,LED14,LED13,LED12,LED11,LED10,LED9,LED8,LED7,LED6,LED5,LED4,LED3,LED2,LED1 | C4_Pretty:RGB_WS2811B | 182 | WS2812B
12 | P1 | C4_Pretty:ISP | 1 | ICSP
13 | P2 | C4_Pretty:Header_FTDI | 1 | FTDI
14 | P3 | C4_Pretty:SIL-2 | 1 | LDR_header
15 | P4 | C4_Pretty:SIL-2 | 1 | Button_Header
16 | P5 | C4_Pretty:JACK_PJ-047a | 1 | BARREL_JACK
17 | P6 | C4_Pretty:r_0805 | 1 | 5VEN_L
18 | P7 | C4_Pretty:STACK-L | 1 | I2C_L
19 | P8 | C4_Pretty:r_0805 | 1 | 5VEN_R
20 | P9 | C4_Pretty:STACK-R | 1 | I2C_R
21 | R1 | C4_Pretty:r_0805 | 1 | 470R
22 | R3,R4 | C4_Pretty:r_0805 | 2 | 1M
23 | R7,R6,R5,R2 | C4_Pretty:r_0805 | 4 | 10K
24 | R9,R8 | C4_Pretty:r_0805 | 2 | 4K7
25 | R12,R13 | C4_Pretty:r_0805 | 2 | 0R
26 | S4,S3,S2,S1 | C4_Pretty:Screw_3mm | 4 | CONN_1
27 | S9,S8,S7,A7,A6,B2 | C4_Pretty:BreakOutPad | 6 | CONN_1
28 | S13,S12,S11,S10 | C4_Pretty:Screw_2mm | 4 | CONN_1
29 | SW1 | C4_Pretty:SW_PB_V_H | 1 | SW_RST
30 | SW2 | C4_Pretty:SW_SMD | 1 | SW_L
31 | SW3 | C4_Pretty:SW_SMD | 1 | SW_R
32 | U1 | C4_Pretty:TQFP32 | 1 | ATMEGA328P
33 | U2 | C4_Pretty:DS3231 | 1 | DS3231N
34 | X1 | C4_Pretty:Xtal_SMD3 | 1 | 16MHz

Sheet: BoM_SCH
Reference | Value | Footprint | Datasheet | Field4 | Field5 | Field6 | Field7 | Field8 | Field9 | Field10 | Field11
A6 | CONN_1 | C4_Pretty:BreakOutPad
A7 | CONN_1 | C4_Pretty:BreakOutPad
B2 | CONN_1 | C4_Pretty:BreakOutPad
BT1 | Batt_RTC | C4_Pretty:CR2032_SMD
C1 | 100n | C4_Pretty:c_0805
C2 | 100p | C4_Pretty:c_0805
C3 | 100n | C4_Pretty:c_0805
C4 | 100p | C4_Pretty:c_0805
C5 | 22p | C4_Pretty:c_0805
C6 | 100n | C4_Pretty:c_0805
C7 | 22p | C4_Pretty:c_0805
C8 | 100n | C4_Pretty:c_0805
C9 | 100n | C4_Pretty:c_0805
C10 | 47u | C4_Pretty:c_2917
C11 | 100n | C4_Pretty:c_0805
C12 | 100n | C4_Pretty:c_0805_led
C13 | 100n | C4_Pretty:c_0805_led
C14 | 100n | C4_Pretty:c_0805_led
C15 | 100n | C4_Pretty:c_0805_led
C16 | 100n | C4_Pretty:c_0805_led
C17 | 100n | C4_Pretty:c_0805_led
C18 | 100n | C4_Pretty:c_0805_led
C19 | 100n | C4_Pretty:c_0805_led
C20 | 100n | C4_Pretty:c_0805_led
C21 | 100n | C4_Pretty:c_0805_led
C22 | 100n | C4_Pretty:c_0805_led
C23 | 100n | C4_Pretty:c_0805_led
C24 | 100n | C4_Pretty:c_0805_led
C25 | 100n | C4_Pretty:c_0805_led
C26 | 100n | C4_Pretty:c_0805_led
C27 | 100n | C4_Pretty:c_0805_led
C28 | 100n | C4_Pretty:c_0805_led
C29 | 100n | C4_Pretty:c_0805_led
C30 | 100n | C4_Pretty:c_0805_led
C31 | 100n | C4_Pretty:c_0805_led
C32 | 100n | C4_Pretty:c_0805_led
C33 | 100n | C4_Pretty:c_0805_led
C34 | 100n | C4_Pretty:c_0805_led
C35 | 100n | C4_Pretty:c_0805_led
C36 | 100n | C4_Pretty:c_0805_led
C37 | 100n | C4_Pretty:c_0805_led
C38 | 100n | C4_Pretty:c_0805_led
C39 | 100n | C4_Pretty:c_0805_led
C40 | 100n | C4_Pretty:c_0805_led
C41 | 100n | C4_Pretty:c_0805_led
C42 | 100n | C4_Pretty:c_0805_led
C43 | 100n | C4_Pretty:c_0805_led
C44 | 100n | C4_Pretty:c_0805_led
C45 | 100n | C4_Pretty:c_0805_led
C46 | 100n | C4_Pretty:c_0805_led
C47 | 100n | C4_Pretty:c_0805_led
C48 | 100n | C4_Pretty:c_0805_led
C49 | 100n | C4_Pretty:c_0805_led
C50 | 100n | C4_Pretty:c_0805_led
C51 | 100n | C4_Pretty:c_0805_led
C52 | 100n | C4_Pretty:c_0805_led
C53 | 100n | C4_Pretty:c_0805_led
C54 | 100n | C4_Pretty:c_0805_led
C55 | 100n | C4_Pretty:c_0805_led
C56 | 100n | C4_Pretty:c_0805_led
C57 | 100n | C4_Pretty:c_0805_led
C58 | 100n | C4_Pretty:c_0805_led
C59 | 100n | C4_Pretty:c_0805_led
C60 | 100n | C4_Pretty:c_0805_led
C61 | 100n | C4_Pretty:c_0805_led
C62 | 100n | C4_Pretty:c_0805_led
C63 | 100n | C4_Pretty:c_0805_led
C64 | 100n | C4_Pretty:c_0805_led
C65 | 100n | C4_Pretty:c_0805_led
C66 | 100n | C4_Pretty:c_0805_led
C67 | 100n | C4_Pretty:c_0805_led
C68 | 100n | C4_Pretty:c_0805_led
C69 | 100n | C4_Pretty:c_0805_led
C70 | 100n | C4_Pretty:c_0805_led
C71 | 100n | C4_Pretty:c_0805_led
C72 | 100n | C4_Pretty:c_0805_led
C73 | 100n | C4_Pretty:c_0805_led
C74 | 100n | C4_Pretty:c_0805_led
C75 | 100n | C4_Pretty:c_0805_led
C76 | 100n | C4_Pretty:c_0805_led
C77 | 100n | C4_Pretty:c_0805_led
C78 | 100n | C4_Pretty:c_0805_led
C79 | 100n | C4_Pretty:c_0805_led
C80 | 100n | C4_Pretty:c_0805_led
C81 | 100n | C4_Pretty:c_0805_led
C82 | 100n | C4_Pretty:c_0805_led
C83 | 100n | C4_Pretty:c_0805_led
C84 | 100n | C4_Pretty:c_0805_led
C85 | 100n | C4_Pretty:c_0805_led
C86 | 100n | C4_Pretty:c_0805_led
C87 | 100n | C4_Pretty:c_0805_led
C88 | 100n | C4_Pretty:c_0805_led
C89 | 100n | C4_Pretty:c_0805_led
C90 | 100n | C4_Pretty:c_0805_led
C91 | 100n | C4_Pretty:c_0805_led
C92 | 100n | C4_Pretty:c_0805_led
C93 | 100n | C4_Pretty:c_0805_led
C94 | 100n | C4_Pretty:c_0805_led
C95 | 100n | C4_Pretty:c_0805_led
C96 | 100n | C4_Pretty:c_0805_led
C97 | 100n | C4_Pretty:c_0805_led
C98 | 100n | C4_Pretty:c_0805_led
C99 | 100n | C4_Pretty:c_0805_led
C100 | 100n | C4_Pretty:c_0805_led
C101 | 100n | C4_Pretty:c_0805_led
C102 | 100n | C4_Pretty:c_0805_led
C103 | 100n | C4_Pretty:c_0805_led
C104 | 100n | C4_Pretty:c_0805_led
C105 | 100n | C4_Pretty:c_0805_led
C106 | 100n | C4_Pretty:c_0805_led
C107 | 100n | C4_Pretty:c_0805_led
C108 | 100n | C4_Pretty:c_0805_led
C109 | 100n | C4_Pretty:c_0805_led
C110 | 100n | C4_Pretty:c_0805_led
C111 | 100n | C4_Pretty:c_0805_led
C112 | 100n | C4_Pretty:c_0805_led
C113 | 100n | C4_Pretty:c_0805_led
C114 | 100n | C4_Pretty:c_0805_led
C115 | 100n | C4_Pretty:c_0805_led
C116 | 100n | C4_Pretty:c_0805_led
C117 | 100n | C4_Pretty:c_0805_led
C118 | 100n | C4_Pretty:c_0805_led
C119 | 100n | C4_Pretty:c_0805_led
C120 | 100n | C4_Pretty:c_0805_led
C121 | 100n | C4_Pretty:c_0805_led
C122 | 100n | C4_Pretty:c_0805_led
C123 | 100n | C4_Pretty:c_0805_led
C124 | 100n | C4_Pretty:c_0805_led
C125 | 100n | C4_Pretty:c_0805_led
C126 | 100n | C4_Pretty:c_0805_led
C127 | 100n | C4_Pretty:c_0805_led
C128 | 100n | C4_Pretty:c_0805_led
C129 | 100n | C4_Pretty:c_0805_led
C130 | 100n | C4_Pretty:c_0805_led
C131 | 100n | C4_Pretty:c_0805_led
C132 | 100n | C4_Pretty:c_0805_led
C133 | 100n | C4_Pretty:c_0805_led
C134 | 100n | C4_Pretty:c_0805_led
C135 | 100n | C4_Pretty:c_0805_led
C136 | 100n | C4_Pretty:c_0805_led
C137 | 100n | C4_Pretty:c_0805_led
C138 | 100n | C4_Pretty:c_0805_led
C139 | 100n | C4_Pretty:c_0805_led
C140 | 100n | C4_Pretty:c_0805_led
C141 | 100n | C4_Pretty:c_0805_led
C142 | 100n | C4_Pretty:c_0805_led
C143 | 100n | C4_Pretty:c_0805_led
C144 | 100n | C4_Pretty:c_0805_led
C145 | 100n | C4_Pretty:c_0805_led
C146 | 100n | C4_Pretty:c_0805_led
C147 | 100n | C4_Pretty:c_0805_led
C148 | 100n | C4_Pretty:c_0805_led
C149 | 100n | C4_Pretty:c_0805_led
C150 | 100n | C4_Pretty:c_0805_led
C151 | 100n | C4_Pretty:c_0805_led
C152 | 100n | C4_Pretty:c_0805_led
C153 | 100n | C4_Pretty:c_0805_led
C154 | 100n | C4_Pretty:c_0805_led
C155 | 100n | C4_Pretty:c_0805_led
C156 | 100n | C4_Pretty:c_0805_led
C157 | 100n | C4_Pretty:c_0805_led
C158 | 100n | C4_Pretty:c_0805_led
C159 | 100n | C4_Pretty:c_0805_led
C160 | 100n | C4_Pretty:c_0805_led
C161 | 100n | C4_Pretty:c_0805_led
C162 | 100n | C4_Pretty:c_0805_led
C163 | 100n | C4_Pretty:c_0805_led
C164 | 100n | C4_Pretty:c_0805_led
C165 | 100n | C4_Pretty:c_0805_led
C166 | 100n | C4_Pretty:c_0805_led
C167 | 100n | C4_Pretty:c_0805_led
C168 | 100n | C4_Pretty:c_0805_led
C169 | 100n | C4_Pretty:c_0805_led
C170 | 100n | C4_Pretty:c_0805_led
C171 | 100n | C4_Pretty:c_0805_led
C172 | 100n | C4_Pretty:c_0805_led
C173 | 100n | C4_Pretty:c_0805_led
C174 | 100n | C4_Pretty:c_0805_led
C175 | 100n | C4_Pretty:c_0805_led
C176 | 100n | C4_Pretty:c_0805_led
C177 | 100n | C4_Pretty:c_0805_led
C178 | 100n | C4_Pretty:c_0805_led
C179 | 100n | C4_Pretty:c_0805_led
C180 | 100n | C4_Pretty:c_0805_led
C181 | 100n | C4_Pretty:c_0805_led
C182 | 100n | C4_Pretty:c_0805_led
C183 | 100n | C4_Pretty:c_0805_led
C184 | 100n | C4_Pretty:c_0805_led
C185 | 100n | C4_Pretty:c_0805_led
C186 | 100n | C4_Pretty:c_0805_led
C187 | 100n | C4_Pretty:c_0805_led
C188 | 100n | C4_Pretty:c_0805_led
C189 | 100n | C4_Pretty:c_0805_led
C190 | 100n | C4_Pretty:c_0805_led
C191 | 100n | C4_Pretty:c_0805_led
C192 | 100n | C4_Pretty:c_0805_led
C193 | 100n | C4_Pretty:c_0805_led
C194 | 47u | C4_Pretty:c_2917
C195 | 47u | C4_Pretty:c_2917
C196 | 47u | C4_Pretty:c_2917
C197 | 100n | C4_Pretty:c_0805
C198 | 100n | C4_Pretty:c_0805
L1 | OSHW | C4_Pretty:Logo_silk_OSHW_6x6mm
L2 | Wyolum | C4_Pretty:Logo-WL3
L3 | Wyolum | C4_Pretty:Logo-WL3
LDR1 | LDR | C4_Pretty:r_0805
LED1 | WS2812B | C4_Pretty:RGB_WS2811B
LED2 | WS2812B | C4_Pretty:RGB_WS2811B
LED3 | WS2812B | C4_Pretty:RGB_WS2811B
LED4 | WS2812B | C4_Pretty:RGB_WS2811B
LED5 | WS2812B | C4_Pretty:RGB_WS2811B
LED6 | WS2812B | C4_Pretty:RGB_WS2811B
LED7 | WS2812B | C4_Pretty:RGB_WS2811B
LED8 | WS2812B | C4_Pretty:RGB_WS2811B
LED9 | WS2812B | C4_Pretty:RGB_WS2811B
LED10 | WS2812B | C4_Pretty:RGB_WS2811B
LED11 | WS2812B | C4_Pretty:RGB_WS2811B
LED12 | WS2812B | C4_Pretty:RGB_WS2811B
LED13 | WS2812B | C4_Pretty:RGB_WS2811B
LED14 | WS2812B | C4_Pretty:RGB_WS2811B
LED15 | WS2812B | C4_Pretty:RGB_WS2811B
LED16 | WS2812B | C4_Pretty:RGB_WS2811B
LED17 | WS2812B | C4_Pretty:RGB_WS2811B
LED18 | WS2812B | C4_Pretty:RGB_WS2811B
LED19 | WS2812B | C4_Pretty:RGB_WS2811B
LED20 | WS2812B | C4_Pretty:RGB_WS2811B
LED21 | WS2812B | C4_Pretty:RGB_WS2811B
LED22 | WS2812B | C4_Pretty:RGB_WS2811B
LED23 | WS2812B | C4_Pretty:RGB_WS2811B
LED24 | WS2812B | C4_Pretty:RGB_WS2811B
LED25 | WS2812B | C4_Pretty:RGB_WS2811B
LED26 | WS2812B | C4_Pretty:RGB_WS2811B
LED27 | WS2812B | C4_Pretty:RGB_WS2811B
LED28 | WS2812B | C4_Pretty:RGB_WS2811B
LED29 | WS2812B | C4_Pretty:RGB_WS2811B
LED30 | WS2812B | C4_Pretty:RGB_WS2811B
LED31 | WS2812B | C4_Pretty:RGB_WS2811B
LED32 | WS2812B | C4_Pretty:RGB_WS2811B
LED33 | WS2812B | C4_Pretty:RGB_WS2811B
LED34 | WS2812B | C4_Pretty:RGB_WS2811B
LED35 | WS2812B | C4_Pretty:RGB_WS2811B
LED36 | WS2812B | C4_Pretty:RGB_WS2811B
LED37 | WS2812B | C4_Pretty:RGB_WS2811B
LED38 | WS2812B | C4_Pretty:RGB_WS2811B
LED39 | WS2812B | C4_Pretty:RGB_WS2811B
LED40 | WS2812B | C4_Pretty:RGB_WS2811B
LED41 | WS2812B | C4_Pretty:RGB_WS2811B
LED42 | WS2812B | C4_Pretty:RGB_WS2811B
LED43 | WS2812B | C4_Pretty:RGB_WS2811B
LED44 | WS2812B | C4_Pretty:RGB_WS2811B
LED45 | WS2812B | C4_Pretty:RGB_WS2811B
LED46 | WS2812B | C4_Pretty:RGB_WS2811B
LED47 | WS2812B | C4_Pretty:RGB_WS2811B
LED48 | WS2812B | C4_Pretty:RGB_WS2811B
LED49 | WS2812B | C4_Pretty:RGB_WS2811B
LED50 | WS2812B | C4_Pretty:RGB_WS2811B
LED51 | WS2812B | C4_Pretty:RGB_WS2811B
LED52 | WS2812B | C4_Pretty:RGB_WS2811B
LED53 | WS2812B | C4_Pretty:RGB_WS2811B
LED54 | WS2812B | C4_Pretty:RGB_WS2811B
LED55 | WS2812B | C4_Pretty:RGB_WS2811B
LED56 | WS2812B | C4_Pretty:RGB_WS2811B
LED57 | WS2812B | C4_Pretty:RGB_WS2811B
LED58 | WS2812B | C4_Pretty:RGB_WS2811B
LED59 | WS2812B | C4_Pretty:RGB_WS2811B
LED60 | WS2812B | C4_Pretty:RGB_WS2811B
LED61 | WS2812B | C4_Pretty:RGB_WS2811B
LED62 | WS2812B | C4_Pretty:RGB_WS2811B
LED63 | WS2812B | C4_Pretty:RGB_WS2811B
LED64 | WS2812B | C4_Pretty:RGB_WS2811B
LED65 | WS2812B | C4_Pretty:RGB_WS2811B
LED66 | WS2812B | C4_Pretty:RGB_WS2811B
LED67 | WS2812B | C4_Pretty:RGB_WS2811B
LED68 | WS2812B | C4_Pretty:RGB_WS2811B
LED69 | WS2812B | C4_Pretty:RGB_WS2811B
LED70 | WS2812B | C4_Pretty:RGB_WS2811B
LED71 | WS2812B | C4_Pretty:RGB_WS2811B
LED72 | WS2812B | C4_Pretty:RGB_WS2811B
LED73 | WS2812B | C4_Pretty:RGB_WS2811B
LED74 | WS2812B | C4_Pretty:RGB_WS2811B
LED75 | WS2812B | C4_Pretty:RGB_WS2811B
LED76 | WS2812B | C4_Pretty:RGB_WS2811B
LED77 | WS2812B | C4_Pretty:RGB_WS2811B
LED78 | WS2812B | C4_Pretty:RGB_WS2811B
LED79 | WS2812B | C4_Pretty:RGB_WS2811B
LED80 | WS2812B | C4_Pretty:RGB_WS2811B
LED81 | WS2812B | C4_Pretty:RGB_WS2811B
LED82 | WS2812B | C4_Pretty:RGB_WS2811B
LED83 | WS2812B | C4_Pretty:RGB_WS2811B
LED84 | WS2812B | C4_Pretty:RGB_WS2811B
LED85 | WS2812B | C4_Pretty:RGB_WS2811B
LED86 | WS2812B | C4_Pretty:RGB_WS2811B
LED87 | WS2812B | C4_Pretty:RGB_WS2811B
LED88 | WS2812B | C4_Pretty:RGB_WS2811B
LED89 | WS2812B | C4_Pretty:RGB_WS2811B
LED90 | WS2812B | C4_Pretty:RGB_WS2811B
LED91 | WS2812B | C4_Pretty:RGB_WS2811B
LED92 | WS2812B | C4_Pretty:RGB_WS2811B
LED93 | WS2812B | C4_Pretty:RGB_WS2811B
LED94 | WS2812B | C4_Pretty:RGB_WS2811B
LED95 | WS2812B | C4_Pretty:RGB_WS2811B
LED96 | WS2812B | C4_Pretty:RGB_WS2811B
LED97 | WS2812B | C4_Pretty:RGB_WS2811B
LED98 | WS2812B | C4_Pretty:RGB_WS2811B
LED99 | WS2812B | C4_Pretty:RGB_WS2811B
LED100 | WS2812B | C4_Pretty:RGB_WS2811B
LED101 | WS2812B | C4_Pretty:RGB_WS2811B
LED102 | WS2812B | C4_Pretty:RGB_WS2811B
LED103 | WS2812B | C4_Pretty:RGB_WS2811B
LED104 | WS2812B | C4_Pretty:RGB_WS2811B
LED105 | WS2812B | C4_Pretty:RGB_WS2811B
LED106 | WS2812B | C4_Pretty:RGB_WS2811B
LED107 | WS2812B | C4_Pretty:RGB_WS2811B
LED108 | WS2812B | C4_Pretty:RGB_WS2811B
LED109 | WS2812B | C4_Pretty:RGB_WS2811B
LED110 | WS2812B | C4_Pretty:RGB_WS2811B
LED111 | WS2812B | C4_Pretty:RGB_WS2811B
LED112 | WS2812B | C4_Pretty:RGB_WS2811B
LED113 | WS2812B | C4_Pretty:RGB_WS2811B
LED114 | WS2812B | C4_Pretty:RGB_WS2811B
LED115 | WS2812B | C4_Pretty:RGB_WS2811B
LED116 | WS2812B | C4_Pretty:RGB_WS2811B
LED117 | WS2812B | C4_Pretty:RGB_WS2811B
LED118 | WS2812B | C4_Pretty:RGB_WS2811B
LED119 | WS2812B | C4_Pretty:RGB_WS2811B
LED120 | WS2812B | C4_Pretty:RGB_WS2811B
LED121 | WS2812B | C4_Pretty:RGB_WS2811B
LED122 | WS2812B | C4_Pretty:RGB_WS2811B
LED123 | WS2812B | C4_Pretty:RGB_WS2811B
LED124 | WS2812B | C4_Pretty:RGB_WS2811B
LED125 | WS2812B | C4_Pretty:RGB_WS2811B
LED126 | WS2812B | C4_Pretty:RGB_WS2811B
LED127 | WS2812B | C4_Pretty:RGB_WS2811B
LED128 | WS2812B | C4_Pretty:RGB_WS2811B
LED129 | WS2812B | C4_Pretty:RGB_WS2811B
LED130 | WS2812B | C4_Pretty:RGB_WS2811B
LED131 | WS2812B | C4_Pretty:RGB_WS2811B
LED132 | WS2812B | C4_Pretty:RGB_WS2811B
LED133 | WS2812B | C4_Pretty:RGB_WS2811B
LED134 | WS2812B | C4_Pretty:RGB_WS2811B
LED135 | WS2812B | C4_Pretty:RGB_WS2811B
LED136 | WS2812B | C4_Pretty:RGB_WS2811B
LED137 | WS2812B | C4_Pretty:RGB_WS2811B
LED138 | WS2812B | C4_Pretty:RGB_WS2811B
LED139 | WS2812B | C4_Pretty:RGB_WS2811B
LED140 | WS2812B | C4_Pretty:RGB_WS2811B
LED141 | WS2812B | C4_Pretty:RGB_WS2811B
LED142 | WS2812B | C4_Pretty:RGB_WS2811B
LED143 | WS2812B | C4_Pretty:RGB_WS2811B
LED144 | WS2812B | C4_Pretty:RGB_WS2811B
LED145 | WS2812B | C4_Pretty:RGB_WS2811B
LED146 | WS2812B | C4_Pretty:RGB_WS2811B
LED147 | WS2812B | C4_Pretty:RGB_WS2811B
LED148 | WS2812B | C4_Pretty:RGB_WS2811B
LED149 | WS2812B | C4_Pretty:RGB_WS2811B
LED150 | WS2812B | C4_Pretty:RGB_WS2811B
LED151 | WS2812B | C4_Pretty:RGB_WS2811B
LED152 | WS2812B | C4_Pretty:RGB_WS2811B
LED153 | WS2812B | C4_Pretty:RGB_WS2811B
LED154 | WS2812B | C4_Pretty:RGB_WS2811B
LED155 | WS2812B | C4_Pretty:RGB_WS2811B
LED156 | WS2812B | C4_Pretty:RGB_WS2811B
LED157 | WS2812B | C4_Pretty:RGB_WS2811B
LED158 | WS2812B | C4_Pretty:RGB_WS2811B
LED159 | WS2812B | C4_Pretty:RGB_WS2811B
LED160 | WS2812B | C4_Pretty:RGB_WS2811B
LED161 | WS2812B | C4_Pretty:RGB_WS2811B
LED162 | WS2812B | C4_Pretty:RGB_WS2811B
LED163 | WS2812B | C4_Pretty:RGB_WS2811B
LED164 | WS2812B | C4_Pretty:RGB_WS2811B
LED165 | WS2812B | C4_Pretty:RGB_WS2811B
LED166 | WS2812B | C4_Pretty:RGB_WS2811B
LED167 | WS2812B | C4_Pretty:RGB_WS2811B
LED168 | WS2812B | C4_Pretty:RGB_WS2811B
LED169 | WS2812B | C4_Pretty:RGB_WS2811B
LED170 | WS2812B | C4_Pretty:RGB_WS2811B
LED171 | WS2812B | C4_Pretty:RGB_WS2811B
LED172 | WS2812B | C4_Pretty:RGB_WS2811B
LED173 | WS2812B | C4_Pretty:RGB_WS2811B
LED174 | WS2812B | C4_Pretty:RGB_WS2811B
LED175 | WS2812B | C4_Pretty:RGB_WS2811B
LED176 | WS2812B | C4_Pretty:RGB_WS2811B
LED177 | WS2812B | C4_Pretty:RGB_WS2811B
LED178 | WS2812B | C4_Pretty:RGB_WS2811B
LED179 | WS2812B | C4_Pretty:RGB_WS2811B
LED180 | WS2812B | C4_Pretty:RGB_WS2811B
LED181 | WS2812B | C4_Pretty:RGB_WS2811B
LED182 | WS2812B | C4_Pretty:RGB_WS2811B
P1 | ICSP | C4_Pretty:ISP
P2 | FTDI | C4_Pretty:Header_FTDI
P3 | LDR_header | C4_Pretty:SIL-2
P4 | Button_Header | C4_Pretty:SIL-2
P5 | BARREL_JACK | C4_Pretty:JACK_PJ-047a
P6 | 5VEN_L | C4_Pretty:r_0805
P7 | I2C_L | C4_Pretty:STACK-L
P8 | 5VEN_R | C4_Pretty:r_0805
P9 | I2C_R | C4_Pretty:STACK-R
R1 | 470R | C4_Pretty:r_0805
R2 | 10K | C4_Pretty:r_0805
R3 | 1M | C4_Pretty:r_0805
R4 | 1M | C4_Pretty:r_0805
R5 | 10K | C4_Pretty:r_0805
R6 | 10K | C4_Pretty:r_0805
R7 | 10K | C4_Pretty:r_0805
R8 | 4K7 | C4_Pretty:r_0805
R9 | 4K7 | C4_Pretty:r_0805
R10 | 10K | C4_Pretty:r_0805
R11 | 10K | C4_Pretty:r_0805
R12 | 0R | C4_Pretty:r_0805
R13 | 0R | C4_Pretty:r_0805
S1 | CONN_1 | C4_Pretty:Screw_3mm
S2 | CONN_1 | C4_Pretty:Screw_3mm
S3 | CONN_1 | C4_Pretty:Screw_3mm
S4 | CONN_1 | C4_Pretty:Screw_3mm
S7 | CONN_1 | C4_Pretty:BreakOutPad
S8 | CONN_1 | C4_Pretty:BreakOutPad
S9 | CONN_1 | C4_Pretty:BreakOutPad
S10 | CONN_1 | C4_Pretty:Screw_2mm
S11 | CONN_1 | C4_Pretty:Screw_2mm
S12 | CONN_1 | C4_Pretty:Screw_2mm
S13 | CONN_1 | C4_Pretty:Screw_2mm
SW1 | SW_RST | C4_Pretty:SW_SMD
SW2 | SW_L | C4_Pretty:SW_SMD
SW3 | SW_R | C4_Pretty:SW_SMD
U1 | ATMEGA328P | C4_Pretty:TQFP32
U2 | DS3231N | C4_Pretty:DS3231
X1 | 16MHz | C4_Pretty:Xtal_SMD3

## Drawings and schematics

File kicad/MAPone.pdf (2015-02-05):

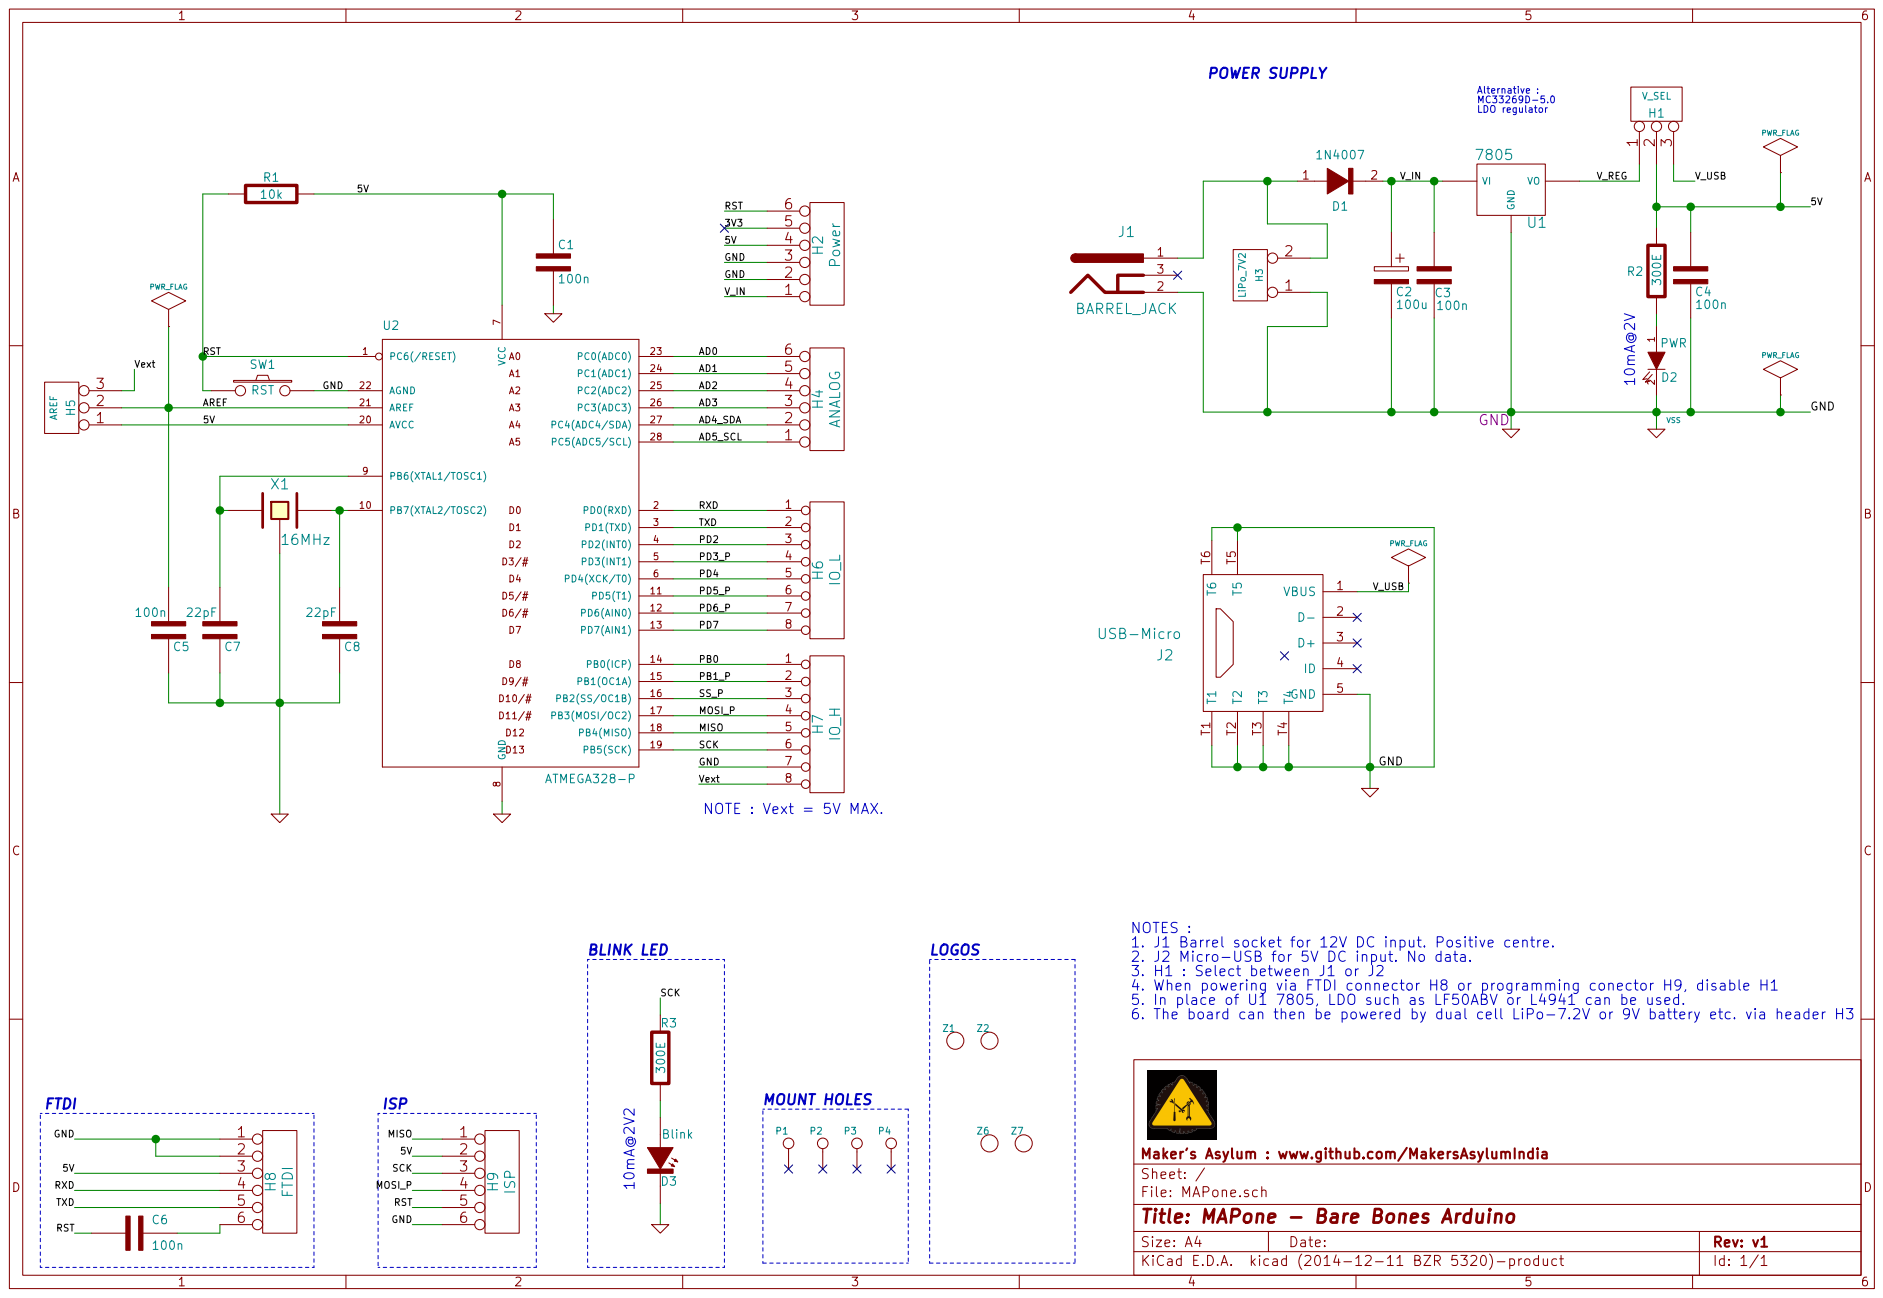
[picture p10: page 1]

8 PB6(XTAL1/TOSC1) 9 PB7(XTAL2/TOSC2) 10 AVCC 20 PD5(T1) 11 AREF 21 PD6(AIN0) 12 AGND 22 PD7(AIN1) 13 PC0(ADC0) 23 PB0(ICP) 14 PC1(ADC1) 24 PB1(OC1A) 15 PC2(ADC2) 25 PB2(SS/OC1B) 16 PC3(ADC3) 26 PB3(MOSI/OC2) 17 PC4(ADC4/SDA) 27 PB4(MISO) 18 PC5(ADC5/SCL) 28 PB5(SCK) 19 U2 ATMEGA328-P

6. The board can then be powered by dual cell LiPo-7.2V or 9V battery etc. via header H3 10mA@2V 10mA@2V2
AD5_SCL AD3 AD2 AD1 AD0 Vext GND

NOTES :
1. J1 Barrel socket for 12V DC input. Positive centre.
2. J2 Micro-USB for 5V DC input. No data.
3. H1 : Select between J1 or J2
4. When powering via FTDI connector H8 or programming conector H9, disable H1
5. In place of U1 7805, LDO such as LF50ABV or L4941 can be used.

File: MAPone.sch Sheet: / Maker's Asylum : www.github.com/MakersAsylumIndia

Id: 1/1 Title: MAPone - Bare Bones Arduino

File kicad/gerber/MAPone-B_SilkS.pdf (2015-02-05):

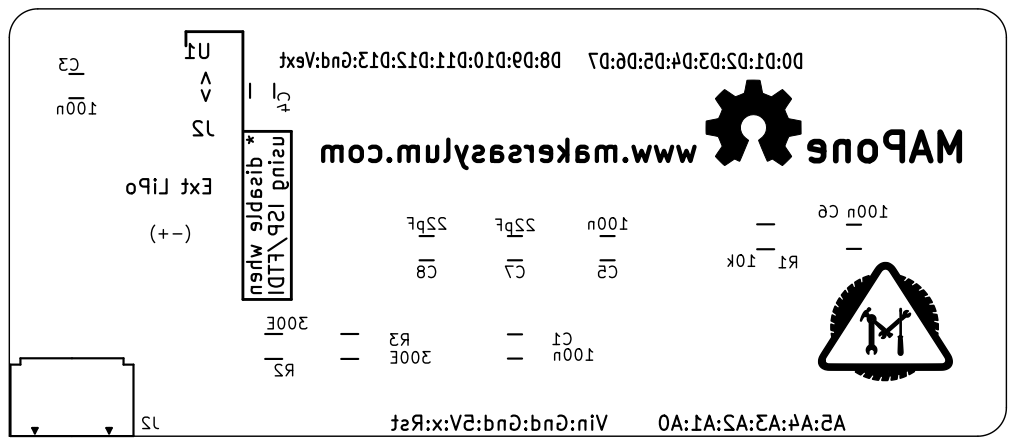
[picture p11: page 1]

File: MAPone.kicad_pcb Sheet: Maker's Asylum : www.github.com/MakersAsylumIndia * disable when using ISP/FTDI Ext LiPo

Id: 1/1 Title: MAPone - Bare Bones Arduino

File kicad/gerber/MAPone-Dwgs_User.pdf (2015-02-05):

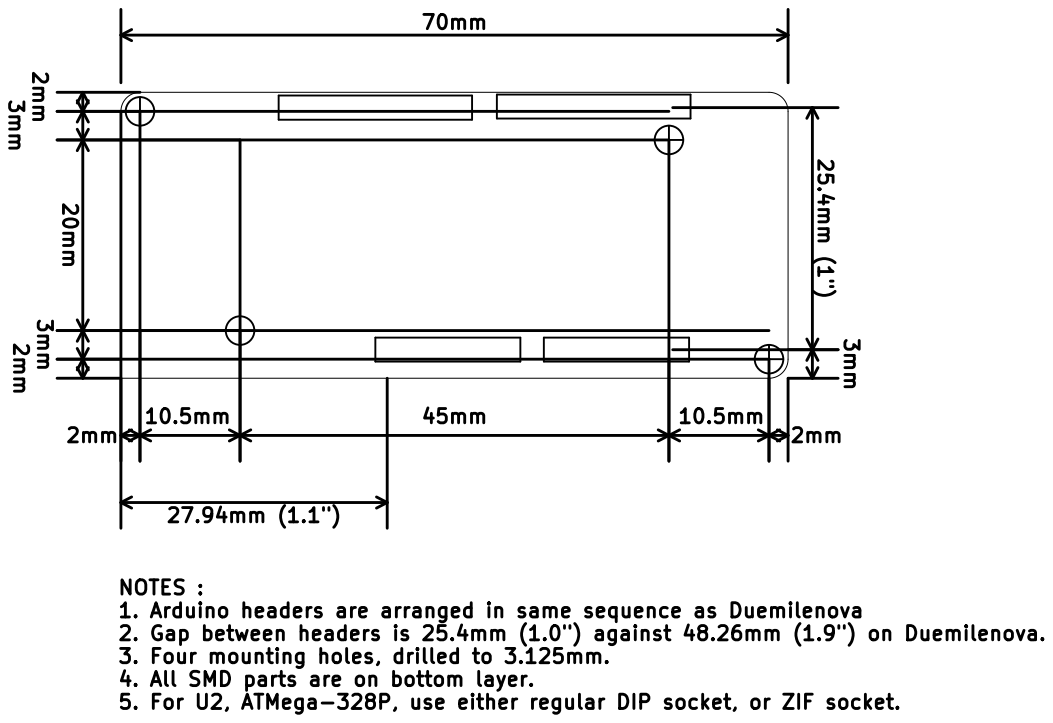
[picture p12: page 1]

27.94mm (1.1") NOTES : 1. Arduino headers are arranged in same sequence as Duemilenova

2. Gap between headers is 25.4mm (1.0") against 48.26mm (1.9") on Duemilenova.
3. Four mounting holes, drilled to 3.125mm.
4. All SMD parts are on bottom layer.

File: MAPone.kicad_pcb Sheet: Maker's Asylum : www.github.com/MakersAsylumIndia

Id: 1/1 Title: MAPone - Bare Bones Arduino

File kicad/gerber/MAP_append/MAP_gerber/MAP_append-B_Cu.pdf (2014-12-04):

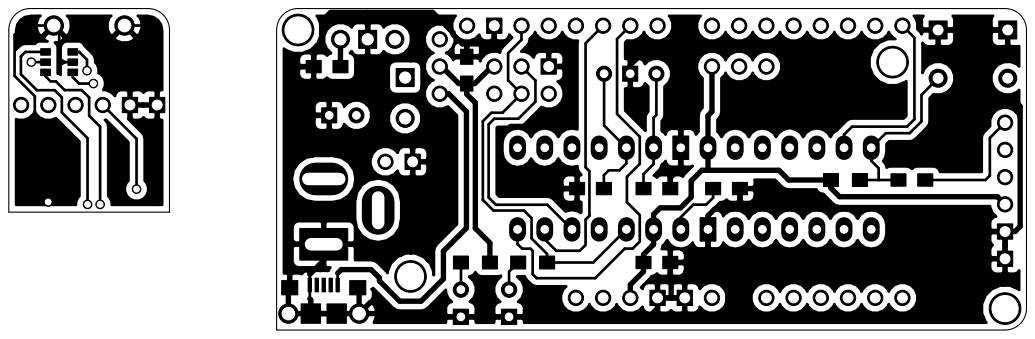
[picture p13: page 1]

File: MAP_append.kicad_pcb Sheet: Maker's Asylum : www.github.com/MakersAsylumIndia

Id: 1/1 Title: MAPusart - USB to USART Bridge using CP2012

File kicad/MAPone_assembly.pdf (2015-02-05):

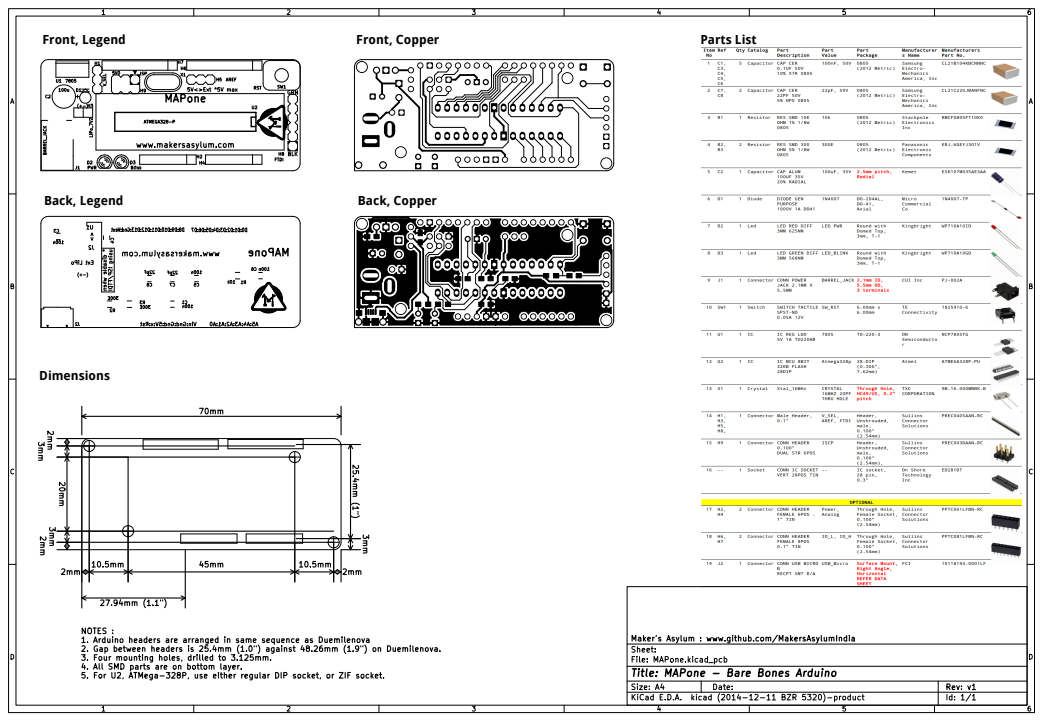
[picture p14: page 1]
Front, Legend; Front, Copper; Back, Legend; Back, Copper; Dimensions; Parts List

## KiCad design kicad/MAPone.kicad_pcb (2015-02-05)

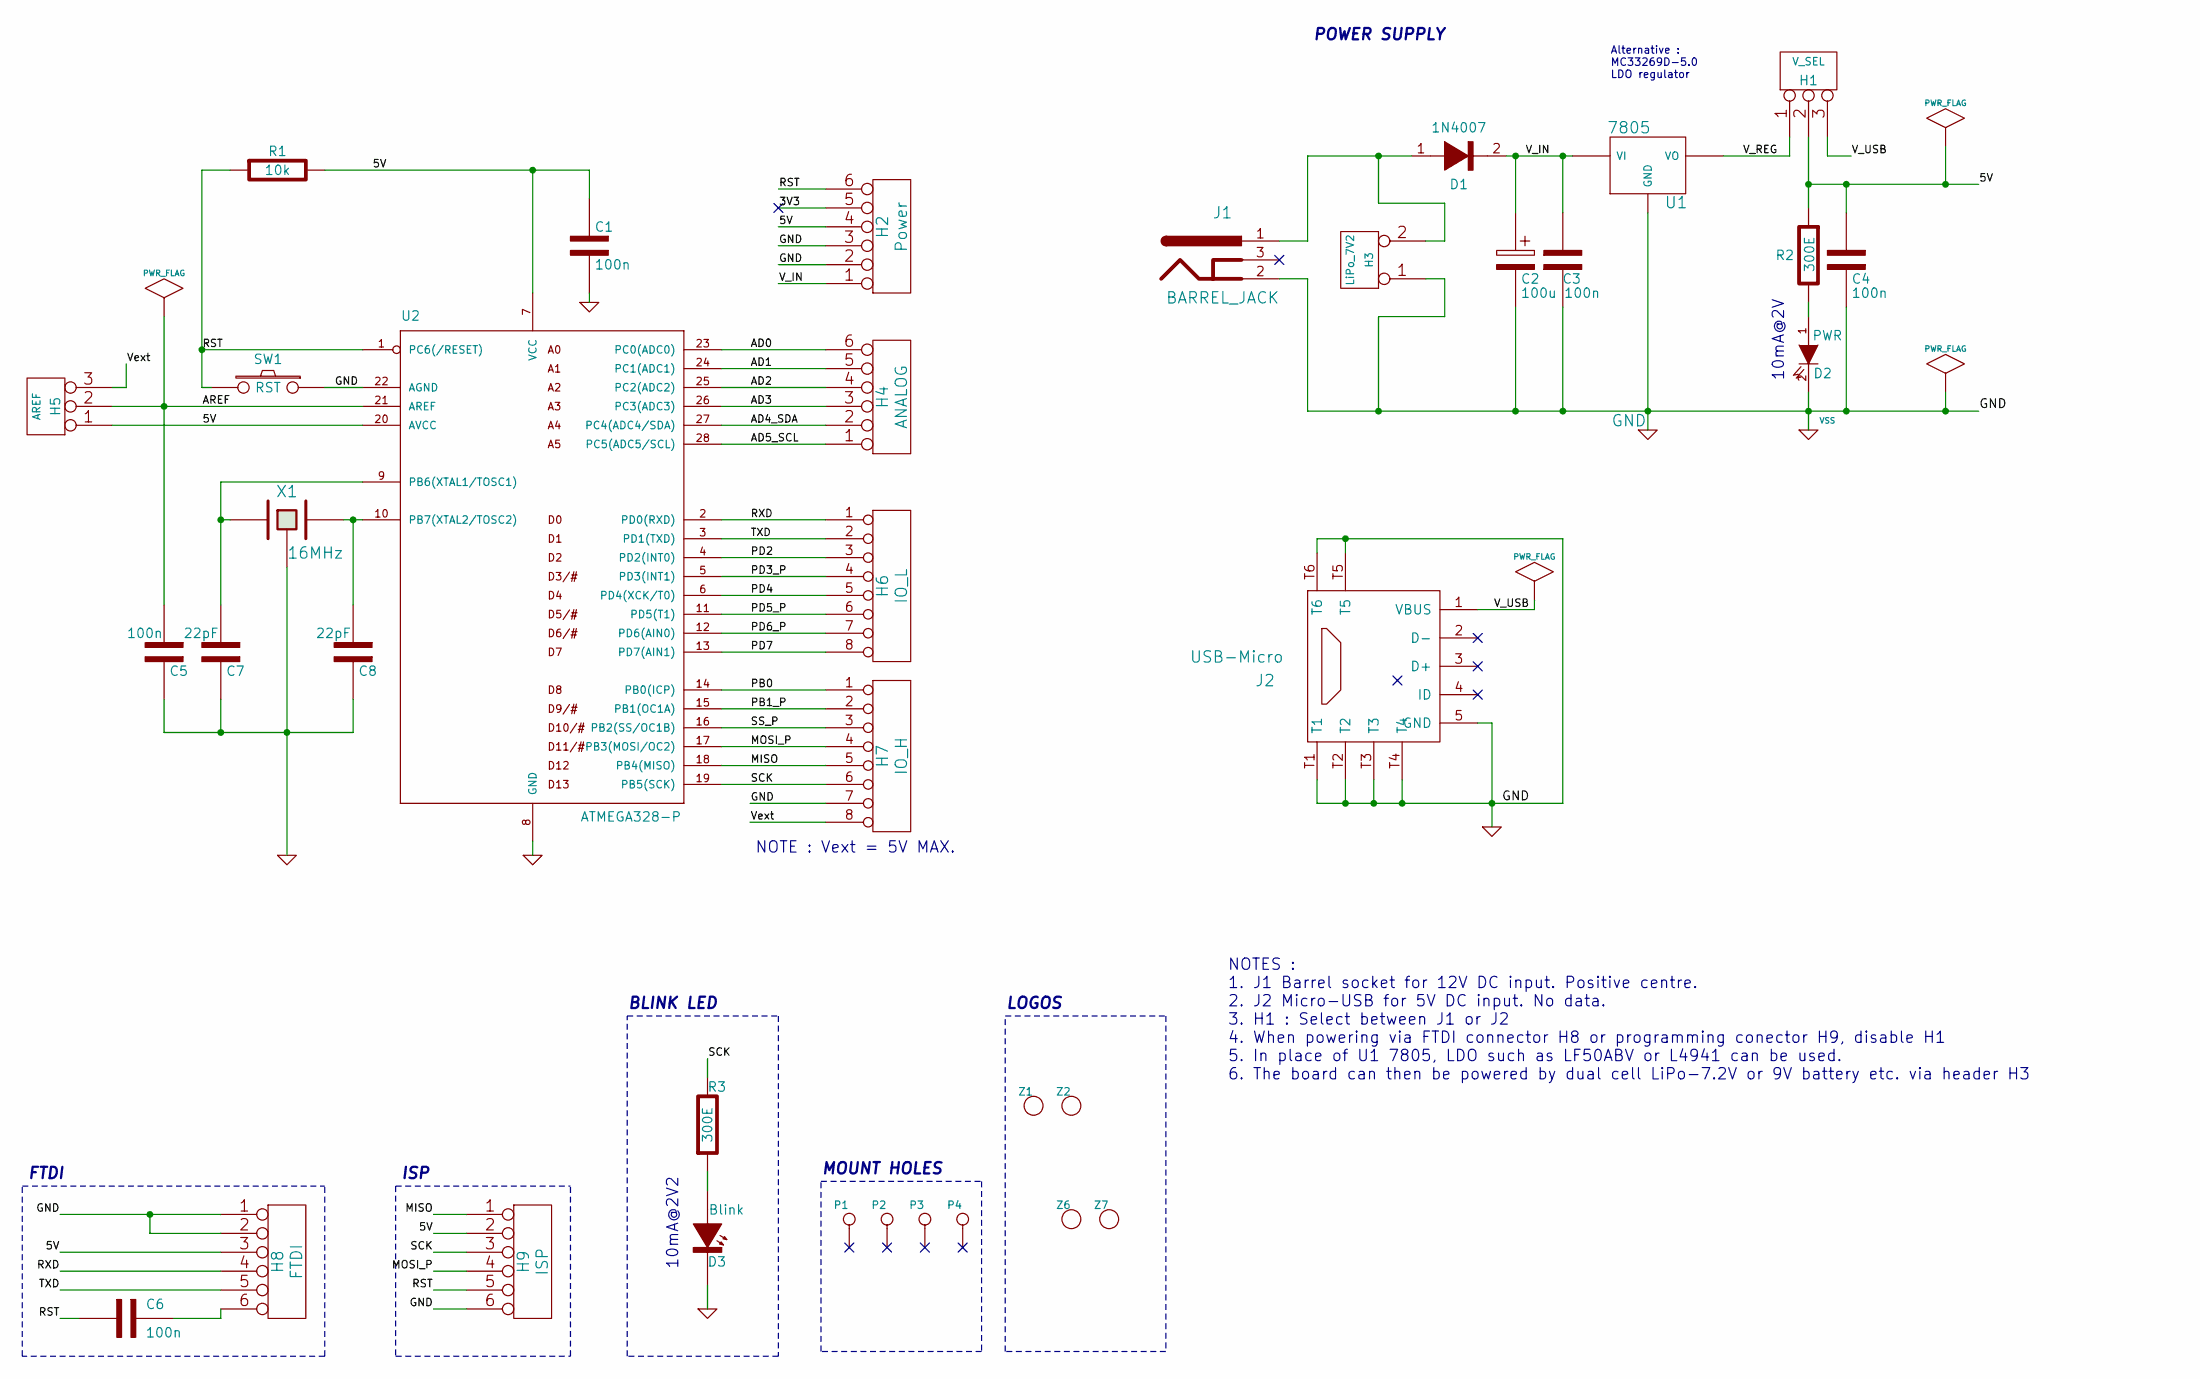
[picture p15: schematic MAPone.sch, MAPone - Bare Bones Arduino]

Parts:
C1, C3, C4, C5, C6: 100n; C_0805_HandSoldering
C2: 100u; Elko_vert_11.2x6.3mm_RM2.5
C7, C8: 22pF; C_0805_HandSoldering
D1: 1N4007; Diode_DO-41_SOD81_Vertical_KathodeUp
D2: PWR; LED-3MM
D3: Blink; LED-3MM
H1: V_SEL; Header_3
H2: Power; Socket_Strip_Straight_1x06
H3: LiPo_7V2; Pin_Header_Straight_1x02
H4: ANALOG; Socket_Strip_Straight_1x06
H5: AREF; Header_A_REF
H6: IO_L; Socket_Strip_Straight_1x08
H7: IO_H; Socket_Strip_Straight_1x08
H8: FTDI; Header_FTDI
H9: ISP; Header_ICSP
J1: BARREL_JACK; JACK_ALIM
J2: USB-Micro; USB_B_Micro
P1, P2, P3, P4: CONN_1; vite_3mm
R1: 10k; R_0805_HandSoldering
R2, R3: 300E; R_0805_HandSoldering
SW1: RST; SW-PB; DigiKey P10884S-ND
U1: 7805; LM78XXV
U2: ATMEGA328-P; DIP-28__300_ELL_ZIF
X1: 16MHz; Crystal_HC49-U_Vertical_3Pin; DigiKey 490-1214-ND
Z1, Z2: CONN_1; MA_Logo2
Z6, Z7: CONN_1; OSHW_6mm

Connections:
/5V: C1.1, C4.1, H1.2 (PM), H2.4, H5.1, H8.3, H9.2, R1.1, R2.2, U2.7 (VCC), U2.20 (AVCC)
/AD0: H4.6, U2.23 (PC0(ADC0))
/AD1: H4.5, U2.24 (PC1(ADC1))
/AD2: H4.4, U2.25 (PC2(ADC2))
/AD3: H4.3, U2.26 (PC3(ADC3))
/AD4_SDA: H4.2, U2.27 (PC4(ADC4/SDA))
/AD5_SCL: H4.1, U2.28 (PC5(ADC5/SCL))
/AREF: C5.1, H5.2 (PM), U2.21 (AREF)
/MISO: H7.5, H9.1, U2.18 (PB4(MISO))
/MOSI_P: H7.4, H9.4, U2.17 (PB3(MOSI/OC2))
/PB0: H7.1, U2.14 (PB0(ICP))
/PB1_P: H7.2, U2.15 (PB1(OC1A))
/PD2: H6.3, U2.4 (PD2(INT0))
/PD3_P: H6.4, U2.5 (PD3(INT1))
/PD4: H6.5, U2.6 (PD4(XCK/T0))
/PD5_P: H6.6, U2.11 (PD5(T1))
/PD6_P: H6.7, U2.12 (PD6(AIN0))
/PD7: H6.8, U2.13 (PD7(AIN1))
/RST: C6.1, H2.6, H9.5, R1.2, SW1.2, U2.1 (PC6(/RESET))
/RXD: H6.1, H8.4, U2.2 (PD0(RXD))
/SCK: H7.6, H9.3, R3.1, U2.19 (PB5(SCK))
/SS_P: H7.3, U2.16 (PB2(SS/OC1B))
/TXD: H6.2, H8.5, U2.3 (PD1(TXD))
/V_IN: C2.1, C3.2, D1.2 (Cathode), H2.1, U1.VI
/V_REG: H1.1, U1.VO
/V_USB: H1.3, J2.1 (VBUS)
/Vext: H5.3, H7.8
GND: C1.2, C2.2, C3.1, C4.2, C5.2, C7.2, C8.2, D2.2 (K), D3.2 (Cathode), H2.2, H2.3, H3.1, H7.7, H8.1, H8.2, H9.6, J1.2, J2.5 (GND), J2.T1, J2.T2, J2.T3, J2.T4, J2.T5, J2.T6, SW1.1, U1.GND, U2.8 (GND), U2.22 (AGND), X1.3
unnamed: C6.2, H8.6
unnamed: C7.1, U2.9 (PB6(XTAL1/TOSC1)), X1.1
unnamed: C8.1, U2.10 (PB7(XTAL2/TOSC2)), X1.2
unnamed: D1.1 (Anode), H3.2 (PM), J1.1
unnamed: D2.1 (A), R2.1
unnamed: D3.1 (Anode), R3.2

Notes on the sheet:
Alternative : MC33269D-5.0 LDO regulator
POWER SUPPLY
ISP
FTDI
BLINK LED
MOUNT HOLES
NOTE : Vext = 5V MAX.
NOTES : 1. J1 Barrel socket for 12V DC input. Positive centre. 2. J2 Micro-USB for 5V DC input. No data. 3. H1 : Select between J1 or J2 4. When powering via FTDI connector H8 or programming conector H9, disable H1 5. In place of U1 7805, LDO such as LF50ABV or L4941 can be used. 6. The board can t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
10mA@2V
10mA@2V2
LOGOS

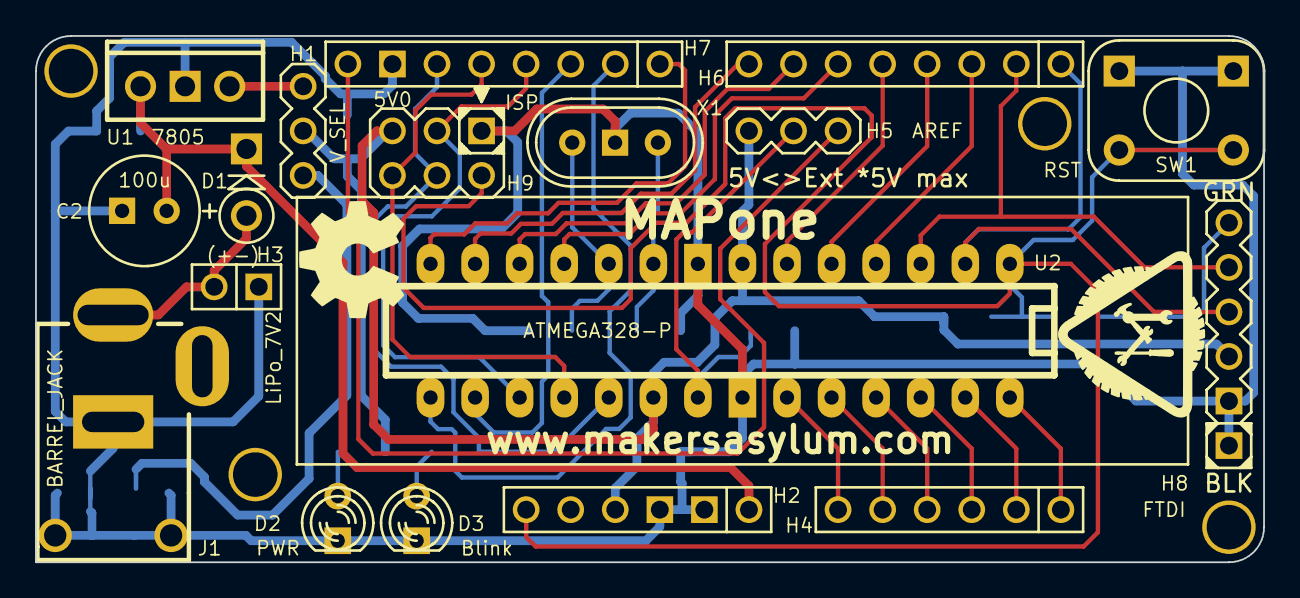
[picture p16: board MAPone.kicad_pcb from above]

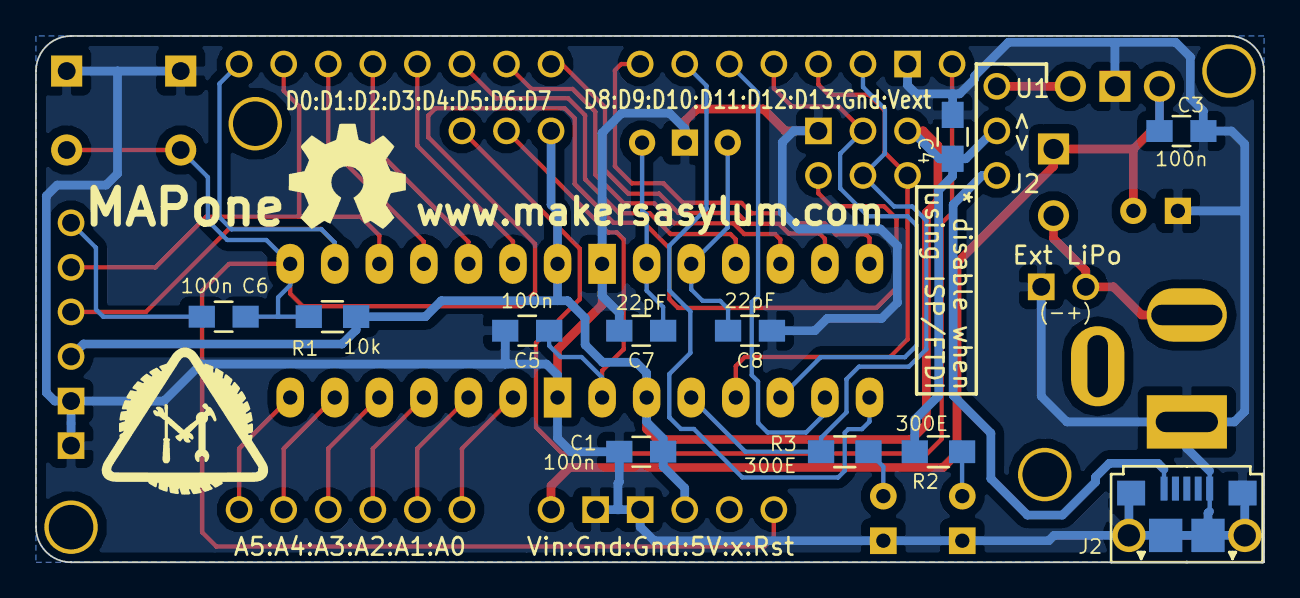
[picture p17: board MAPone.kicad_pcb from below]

Board: 2 copper layers, 70.0 x 30.0 mm, 37 parts (13 on the bottom side), 34 nets.

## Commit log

2014-11-17 first commit for MAPone just to set things up
    [MAPone.sch]
2014-11-18 MAPone schematic, work in progress
    [MAPone.kicad_pcb]
2014-11-21 Added usb uart sch
    [UsbUartBridge.sch]
2014-11-25 MAPone schematic review + PCB initialized
    [MAPone.kicad_pcb]
2014-11-26 MAPone PCB work in progress
    [$MAPone.sch, MAPone.dsn, MAPone.kicad_pcb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]
2014-11-28 MAPone schematic/pcb complete
    [$MAPone.sch, MAPone.dsn, MAPone.sch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]
2014-11-29 MAPone Schematic, PCB, BoM complete. USB<>UART PCB Pending
    [MAPone-B_Cu.gbr, MAPone-B_Mask.gbr, MAPone-B_SilkS.gbr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]
2014-11-30 MAPone Schematic, PCB, BoM complete. USB<>UART PCB work in progress
    [MAPone.kicad_pcb, MAPone.sch, MAPone_BoM_sch.csv]
2014-12-01 MAPone USB<>USART complete. preliminary gerbers generated
    [MAPone(copy).kicad_pcb, MAPone(panel).kicad_pcb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]
2014-12-01 MAPone changed header locations to fit Breadboard instead of Arduino
    [MAPone(copy).kicad_pcb, MAPone(panel).kicad_pcb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]
2014-12-01 MAPone realigned headers to fit 0.1 breadboard
    [MAPone-B_Cu.gbl, MAPone-B_Mask.gbs, MAPone-B_SilkS.gbo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]
2014-12-02 finalized schematic design
    [UsbUartBridge.sch]
2014-12-02 MAPone made MAPusart smaller
    [MAPone.kicad_pcb, MAPone.sch, USB_UART.sch]
2014-12-02 MAPone hived off USB<>UART bridge to separate project MAPusart
    [MAPone(usart).kicad_pcb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]
2014-12-03 MAPone complete and ready for prototyping
    [MAPone-B_Cu.gbl, MAPone-B_Mask.gbs, MAPone-B_SilkS.gbo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]
2014-12-04 MAPone & MAPusart made a common gerbe
    [MAP_append-B_Cu.gbl, MAP_append-B_Mask.gbs, MAP_append-B_Paste.gbp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]
2014-12-09 MAPone updated BoM for visha
    [MAPone_BoM_Visha.ods]
2015-02-05 BoM update, added assemby instructions
    [MAP_append-B_Cu.gbl, MAP_append-B_Mask.gbs, MAP_append-B_Paste.gbp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]
